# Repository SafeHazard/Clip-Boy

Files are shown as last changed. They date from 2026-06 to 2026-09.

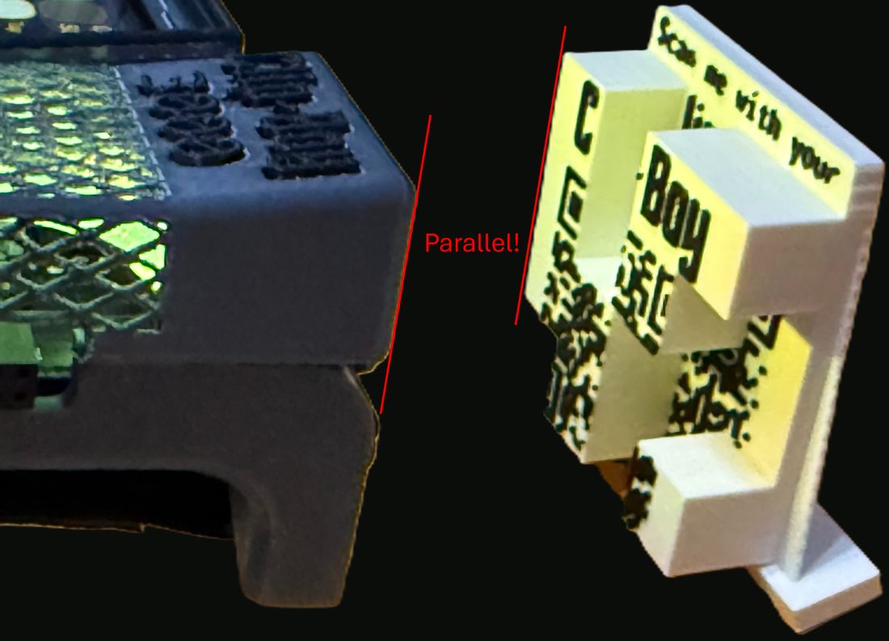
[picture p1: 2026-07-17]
help/img/scan-parallel.jpg

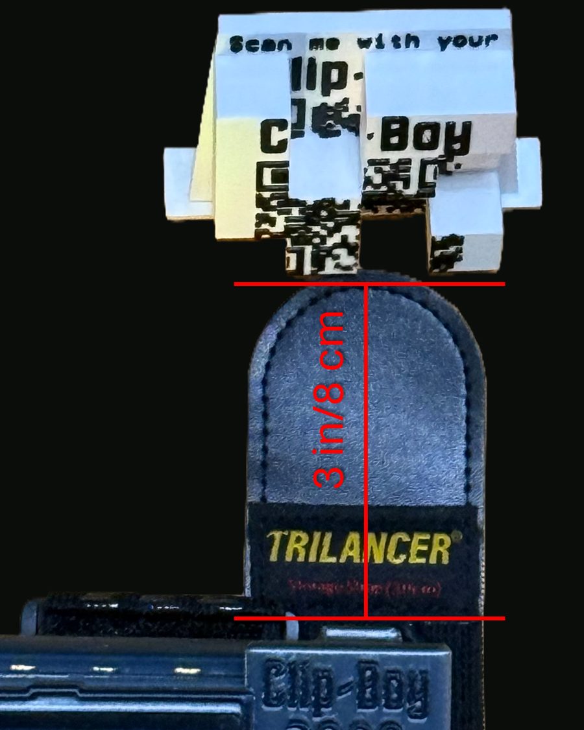
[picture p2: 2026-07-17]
help/img/scan-distance.jpg

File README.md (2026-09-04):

# Clip-Boy

Clip-Boy is an open-source DEF CON electronic badge with a digital wasteland
survivor soul, running on an ESP32-S3 with an LVGL touch UI.

> **Want one?** https://brycebadges.com  -  Docs & help: https://safehazard.github.io/Clip-Boy

## Who built this
Clip-Boy is Bryce's project. He did the PCB design, the enclosure, and the
firmware. Commits land under `tropicsquirrel` (his dad) because the build toolchain
lives on that machine - it reflects where the work was committed from, not who did
it. Claude is used heavily throughout; see `Clip-Boy/AI-DISCLOSURE.md`. Outside
contributions are credited below and in the commit/PR history.

## Repository layout
- **`Clip-Boy/`** - the firmware (Arduino sketch `Clip-Boy.ino` + sources, vendored
  `Clip-Boy/libs/`, build scripts in `Clip-Boy/scripts/`).
- **`Clip-Boy/hardware/`** - open-hardware package to build your own badge: bill of
  materials (`BOM_*.md`/`.csv`), PCB source (`Clip-Boy-PCBs.eprj2`, EasyEDA) + fab-ready
  Gerbers for both boards, the enclosure (`Enclosure-*.step`), and the OmniTag HR-code
  master (`omnitag.3mf`).
- **`Clip-Boy/tags/`** + **`Clip-Boy/stands/`** - ready-to-print `.3mf` models: one
  collectible HR-code tag per ID, plus display stands (regenerate any time with
  `Clip-Boy/scripts/build_all_tags.py`). Print assets only - not needed to compile.
- `index.html`, `postcon/` - the project's web pages. `README.md`, `LICENSE`.

## License
**GPLv3** (`LICENSE`, repo root) - forced by linking the GPL `audio-tools` library.
First-party code is also offered under MIT for audio-tools-free builds. Third-party
components: `Clip-Boy/THIRD_PARTY.md`. AI disclosure: `Clip-Boy/AI-DISCLOSURE.md`.
Acceptable use: `Clip-Boy/acceptable_use.md`.

## Credits
- **ESP32 Marauder** by **[JustCallMeKoko](https://github.com/justcallmekoko)**
  ([justcallmekoko/ESP32Marauder](https://github.com/justcallmekoko/ESP32Marauder)) - the
  backbone of the badge's WiFi/Bluetooth recon toolset.
- **Drone Remote-ID detector** (ASTM F3411 / Open Drone ID) contributed by
  **[zenrandom](https://github.com/zenrandom)** - the companion transmitter/simulator toolkit
  lives at **[SafeHazard/drone-remoteid](https://github.com/SafeHazard/drone-remoteid)**.

Full on-device credits are under **Settings > Credits**; third-party components in
`Clip-Boy/THIRD_PARTY.md`.

## Build setup
Versions are pinned for reproducibility:
- **Git Bash** (Windows) to run the build scripts: https://git-scm.com/download/win
  (macOS/Linux already have bash). **Python 3.9+**: https://www.python.org/downloads/
- **`arduino-cli`** (1.4.x).
- **ESP32 core `esp32:esp32@2.0.10`** - REQUIRED, exact version (what the signed
  releases are built with; a different core = a different, non-reproducible binary):
  ```bash
  arduino-cli core install esp32:esp32@2.0.10
  ```
  `build.sh` enforces this and injects the ClipBoy linker flags itself, so **no
  `platform.txt` hand-patching** is needed (unlike a stock Marauder setup).
- Third-party libraries are **vendored** in `Clip-Boy/libs/` - nothing to fetch.

## Build
```bash
cd Clip-Boy
bash scripts/build.sh              # Sn34k-Boy (default, listen-only)
bash scripts/build.sh --res34rch   # Res34rch-Boy (active research tools)
```
Flags compose: `--test`, `--rift` (alt boot screen), `--upload --port COMx`.

## Reproducibility
Builds are deterministic (stamp derived from the commit or a pinned `VERSION`, and
the build path is stripped from the image). From the exact release commit (with the
real `secret.h` + the release `VERSION`), the owner reproduces the signed release
byte-for-byte; a public builder gets a **functionally identical** badge (a fixed ~64
bytes of metadata differ: the ELF self-hash + the esptool image hash). The sketch is
`Clip-Boy.ino` here; the official signed releases are built from the same name.

## The ARG secret
The badge's ARG finale derives phone-unlock codes from a private HMAC key that is
**not** in this repo: `arg_unlock.h` compiles an all-zero placeholder by default, so
the firmware builds and runs (everything works except matching the live phone/IVR).
Define your own 32-byte key to run your own finale.

## Fonts (verify licensing for YOUR use)
The UI typeface (**monofonto**) and tag typeface (**Trek**) are **not included**;
the pre-generated glyph headers (`ui_font_pipboy_*.c`) ARE, so the firmware builds
without them. You only need the `.otf` files to *regenerate* fonts or build the tags.
We don't host or vouch for these fonts - check the license for your use:
monofonto https://www.dafont.com/monofonto.font  -  Trek https://font.download/font/trek

## Legal
Clip-Boy is an independent, original design. It is **not affiliated with, endorsed
by, or sponsored by** any other company, and it is not a replica of any existing
product. Use the badge's tools only on networks and devices you own or are
authorized to test - see `Clip-Boy/acceptable_use.md`.

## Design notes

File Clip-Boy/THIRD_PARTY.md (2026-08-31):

# Third-party libraries (vendored)

To make a fresh clone build with no external fetches, the third-party Arduino
libraries Clip-Boy links are **vendored** into [`libs/`](libs) — copied in and
trimmed to what compiles (each library's `src/`, root sources, manifest, and
license; `examples/`/`docs/`/`tests/` removed). Re-vendor with
[`scripts/vendor_libs.sh`](scripts/vendor_libs.sh).

Each library keeps its own license file under `libs/<name>/` — **that file is
authoritative.** The table below records provenance (version + upstream) and the
license as a convenience; see also [`LICENSE.md`](LICENSE.md). The combined
firmware is GPLv3 (see `LICENSE.md` for why).

| Library | Version | Upstream | License |
|---|---|---|---|
| lvgl | 9.2.0 | github.com/lvgl/lvgl | MIT |
| LovyanGFX | 1.2.19 | github.com/lovyan03/LovyanGFX | BSD-2-Clause (FreeBSD) |
| audio-tools | 1.1.2 | github.com/pschatzmann/arduino-audio-tools | GPL-3.0 |
| minimp3 | 0.1.0 | github.com/pschatzmann/arduino-minimp3 (lieff/minimp3) | CC0-1.0 (public domain) |
| NimBLE-Arduino | 2.3.7 | github.com/h2zero/NimBLE-Arduino | Apache-2.0 |
| ArduinoJson | 7.4.2 | github.com/bblanchon/ArduinoJson | MIT |
| Adafruit_NeoPixel | 1.15.2 | github.com/adafruit/Adafruit_NeoPixel | LGPL-3.0 |
| SparkFun_VL53L5CX_Arduino_Library | 1.0.3 | github.com/sparkfun/SparkFun_VL53L5CX_Arduino_Library | MIT |
| ESPAsyncWebServer | 2.10.4 | github.com/mathieucarbou/ESPAsyncWebServer | LGPL-3.0 |
| AsyncTCP | 1.1.4 | github.com/mathieucarbou/AsyncTCP | LGPL-3.0 |
| ESP32Ping | 1.7 | github.com/marian-craciunescu/ESP32Ping | (see library) |
| LinkedList | 1.3.3 | github.com/ivanseidel/LinkedList | MIT |
| lz4-1.10.0 | 1.10.0 | github.com/lz4/lz4 (Arduino packaging) | BSD-2-Clause |
| ClipBoy | 1.0.0 | fork of github.com/justcallmekoko/ESP32Marauder | MIT |
| opendroneid-core-c | vendored source | github.com/opendroneid/opendroneid-core-c | Apache-2.0 |
| ClipBoyTheremin | 1.0.0 | first-party (this project) | GPL-3.0 |
| LovyanInit-Waveshare | 0.1.0 | first-party (this project) | GPL-3.0 |
| HRCode4x4 | 1.0.0 | first-party (this project) | GPL-3.0 |
| HRScanGuidance | 0.1.0 | first-party (this project) | GPL-3.0 |

**opendroneid-core-c** (the ASTM F3411 / Open Drone ID decoder that powers the
Detect ▸ Drone ID Remote-ID tool) is vendored as source *inside* the ClipBoy
library — `libs/ClipBoy/src/odid_decode.c` + `opendroneid.h` — rather than as its
own `libs/<name>/` directory. Its Apache-2.0 license text is kept beside those
files at `libs/ClipBoy/src/LICENSE.opendroneid`, and each file retains its SPDX
`Apache-2.0` header + `Copyright (C) 2019 Intel Corporation`. Apache-2.0 is
one-way compatible with the combined GPLv3 firmware.

`libs/lv_conf.h` is our LVGL configuration (LVGL reads it from the folder above
`libs/lvgl/`). Notably `LV_USE_FS_ARDUINO_ESP_LITTLEFS = 0` — see CLAUDE.md.

## Fonts

| Font | Source | License | Used for |
|---|---|---|---|
| Monofonto | Larabie Fonts (external, not committed) | freeware; embedded glyphs only | `ui_font_pipboy_*.c` (the Pip-Boy UI typeface) |
| Noto Emoji | google/fonts `ofl/notoemoji` (static instance in [`assets/fonts/`](assets/fonts)) | OFL-1.1 (`assets/fonts/OFL.txt`) | `ui_font_emoji_14.c` — 24-emoji fallback subset |

The `ui_font_*.c` files are **generated, committed artifacts** (the rendered
glyph bitmaps, not the source outlines). Regenerate with
[`scripts/build_fonts.sh`](scripts/build_fonts.sh). Monofonto's OTF is not
redistributed (font EULA); set `MONOFONTO_OTF` to point the script at it. Noto
Emoji is OFL, so its static instance is vendored for reproducibility.

## Local modifications to vendored libraries

Kept minimal; each is commented in-place with a `Clip-Boy local patch` marker so
it survives review and is easy to re-apply after a re-vendor.

- **SparkFun_VL53L5CX_Arduino_Library** — `begin()` is made idempotent
  (`SparkFun_VL53L5CX_Library.cpp`): it now frees `Dev` + `VL53L5CX_i2c` before
  re-`new`-ing them, and the two pointers are default-initialized to `nullptr`
  in the header. Upstream `begin()` allocates both unconditionally with no
  destructor, so every repeated `begin()` orphaned ~2.7 KB. The theremin
  re-`begin()`s the sensor on each enable, which leaked ~2,768 B per on/off
  cycle (caught by `scripts/tests/test_mutual_exclusion.py` / `probe_leak.py`).
  Re-apply if you re-vendor this library.

- **ClipBoy (PCAP single-owner + LittleFS fallback, DC34-147)** — the host badge
  owns the one global Arduino `SD` (mounted on HSPI in `coll_init`), so ClipBoy
  must not re-`SD.begin()`. Patches: `ClipBoyMarauder::setSDAvailable(bool)`
  (`ClipBoyMarauder.cpp/.h`) lets the badge flag the card up so PCAP uses the
  shared mount; `WiFiScan::startPcap` (`WiFiScan.cpp`, + `#include <LittleFS.h>`)
  prefers SD and falls back to the badge's LittleFS partition (size-capped to
  free − 768 KB so a capture can't starve CSV/.sav/radio data); `Buffer`
  (`Buffer.cpp/.h`) gains `setMaxBytes()` + a `writtenBytes` cap enforced in
  `saveFs()`. Each marked `Clip-Boy local patch (DC34-147)`. Re-apply on
  re-vendor.

- **ClipBoy (Settings in-memory only, no SPIFFS rewrite, DC34-147 perf)** —
  `Settings::saveSetting<bool>` (both `bool` and `String` value overloads,
  `Settings.cpp`) no longer rewrites `/settings.json` to SPIFFS; it updates only the
  in-memory `json_settings_string` that `loadSetting<>()` reads. The full-file
  re-serialize was a ~1-2s synchronous flash write that froze the UI when SavePCAP was
  toggled from a touch handler. Clip-Boy relies on none of Marauder's SPIFFS
  persistence (SavePCAP re-syncs from our NVS every boot; WiFi creds pass directly to
  `joinWiFi`). Marked `Clip-Boy local patch (DC34-147 perf)`. Re-apply on re-vendor.

- **ClipBoy (PCAP-only capture gated on 'Allow PCAP Saving', DC34-147)** — Raw/PCAP and
  PMKID/EAPOL are file-only captures; with saving off they'd run and write nothing. Gated
  at two layers so EVERY entry path errors cleanly: the Marauder CLI handlers `sniffraw`
  and `sniffpmkid` (`CommandLine.cpp`) return early with a message; `WiFiScan::RunRawScan`
  (pcap branch only — signal-strength monitor stays available) and `RunEapolScan`
  (`WiFiScan.cpp`) bail before `startPcap`. Gate reads `settings_obj.loadSetting<bool>
  ("SavePCAP")`. Marked `Clip-Boy local patch (DC34-147)`. Re-apply on re-vendor.

- **ClipBoy (MAC-tracker Serial writes made non-blocking, DC34)** — `WiFiScan::updateTrackerUI`
  (`WiFiScan.cpp`) ran every 1s on core 1 (via `cb.loop()` immediately before
  `lv_timer_handler`) and emitted ~21 unconditional `Serial` writes/sec. With no host
  draining the USB-CDC TX buffer each `write` blocked up to `setTxTimeoutMs` (50ms),
  stalling core 1 ~1s out of every 1s → the MAC-tracker UI froze regardless of packet
  density. Each write (`---`, `FOLLOWING`, per-entry MAC/frame line) is now guarded on
  `Serial.availableForWrite()`, so a serial-CLI user still sees the dump (their monitor
  drains the buffer → room available) while a touch-UI user with no reader skips it (buffer
  full) and never blocks. Deliberately NOT `DEBUG_VERBOSE`-gated, to preserve CLI output.
  Marked `Clip-Boy local patch (DC34)`. Re-apply on re-vendor.

- **ClipBoy (Raw/PCAP UI-freeze: rate-limit the pcap flush, DC34)** — `ClipBoyMarauder::loop()`
  (`ClipBoyMarauder.cpp`) called `buffer_obj.save()` EVERY loop; `Buffer::save`/`saveFs` does a
  full open+append+close to SD/LittleFS, and during Raw/PCAP capture the RX buffer is refilled
  continuously, so core 1 did tens of ms of blocking file I/O per loop right before
  `lv_timer_handler()` -> the UI froze. Now flushed at most every 150ms (RAM double-buffer absorbs
  the gap; `save()` early-returns when empty, so non-capture tools are unaffected). Marked
  `Clip-Boy local patch (DC34)`. Re-apply on re-vendor.

- **ClipBoy (Raw/PCAP Serial storm made non-blocking, DC34)** — `WiFiScan::renderRawStats`
  (`WiFiScan.cpp`) emitted ~11 unconditional `Serial.println` at 1Hz on core 1; with no host
  draining USB-CDC each blocked up to `setTxTimeoutMs` (50ms) -> ~0.5s core-1 stall/sec. Same

  > ⚠ 2026-07-27: the badge now runs a **0 ms** TX timeout until a host actually reads it
  > (`cb_serial_tx_relax()` in `Clip-Boy.ino`), so the no-reader case no longer blocks.
  > These guards still apply when a monitor IS attached. Measured: the 50 ms default was
  > costing every passive WiFi tool ~60% of its frames (`docs/test-reports/h1-cdc-stall-2026-07-27.md`).
  fix as the MAC dump: the whole block is guarded on `Serial.availableForWrite()` (a serial-CLI
  reader still sees it; no reader skips it). Marked `Clip-Boy local patch (DC34)`. Re-apply on re-vendor.

- **ClipBoy (stale-accumulator clean-slate on tool start, DC34)** — Marauder-side accumulators
  the UI reads persisted across tool switches, so a tool could display a PRIOR tool's data (e.g.
  Raw/PCAP showed a stale `num_probe` from a Monitor run; MAC Tracker/BT/Flock/Pwnagotchi lists
  showed old rows on re-open). `StopScan` only resets `*_frames` (not `num_*`) and never touched
  the device lists; three `clear*` fns were dead code. Added `ClipBoyMarauder::resetDisplayAccumulators()`
  (`ClipBoyMarauder.cpp/.h`) — called on every tool start from `dispatch_clipboy_action` — which
  runs `resetPacketCounters()` + `clearBTDevices/clearFlockDevices/clearPwnagotchis` (were dead) +
  two new `WiFiScan::clearMacTracker()` (wipes the `mac_entries` hash table `clearMacHistory` misses)
  and `clearChannelActivity()` (`WiFiScan.cpp/.h`). Deliberately does NOT clear the AP/STA/SSID
  lists (select-then-run inputs). Also exposed `reqFrames`/`respFrames` in `CBPacketCounters` so
  Raw/PCAP shows real probe counts. Marked `Clip-Boy local patch (DC34)`. Re-apply on re-vendor.

- **ClipBoy (Raw/PCAP channel hop + selector, DC34)** — Raw/PCAP was FIXED-channel (parked on
  whatever `set_channel` it inherited), so it captured 0 beacons on a quiet channel. `packetRateLoop`
  (`WiFiScan.cpp`) now `channelHop()`s ~1s/channel during `WIFI_SCAN_RAW_CAPTURE` when the new
  `raw_hop` flag is set (EAPOL is never hopped — a handshake must stay on the target channel). Added
  `WiFiScan::setRawChannel(uint8_t)` + `ClipBoyMarauder::setRawCaptureChannel(uint8_t)` (0 = hop the
  band = the UI "Hop (all)" default; 1-14 = lock via `changeChannel`). The UI adds a Channel dropdown
  to the Raw/PCAP pane. Marked `Clip-Boy local patch (DC34)`. Re-apply on re-vendor.

- **ClipBoy (EAPOL capture: counter + target-channel lock, DC34)** — the badge never registered
  EAPOL. Two bugs in `WiFiScan.cpp`: (1) Raw/PCAP's `0x888e` ethertype check was nested under the
  `WIFI_PKT_MGMT` branch, but EAPOL is a 802.11 DATA frame -> it fell into `data_frames++` and the
  check never ran (EAP:0 while the handshake WAS written to the pcap); moved it into the data branch.
  (2) `RunEapolScan` sat on a stale `set_channel` and the EAPOL loop hopped all 14 channels every 2s,
  so a <100ms handshake almost never coincided; now it locks to the SELECTED AP's channel and only
  hops (`eapol_hop`) when no AP is selected. Marked `Clip-Boy local patch (DC34)`. Re-apply on re-vendor.

- **ClipBoy (large PSRAM capture buffer, DC34)** — `Buffer` used two 8KB (`BUF_SIZE`) internal-RAM
  buffers; on a capture burst (a 4-way handshake amid beacons) both filled before the slow SD write
  drained and packets dropped (missed EAPOL msg 2/4). Now lazily allocates two `CB_PCAP_BUF_SIZE`
  (128KB) PSRAM buffers on first capture (`Buffer::ensureBuffers`, `Buffer.cpp/.h`), with `bufCap`
  driving the fill checks and a fallback to `BUF_SIZE` internal RAM if `ps_malloc` fails. Marked
  `Clip-Boy local patch (DC34)`. Re-apply on re-vendor.

- **ClipBoy (expose Channel-Activity page, DC34)** — the ranged channel-activity hop only
  sweeps 7 channels per `activity_page` (page 1 = ch 1-7, page 2 = ch 8-14) and the vendored
  default is stuck at page 1, so a "channels 1-14" histogram left ch 8-14 permanently empty.
  Added `ClipBoyMarauder::setChannelActivityPage(uint8_t)` + `getChannelActivityPage()`
  (`ClipBoyMarauder.cpp/.h`) writing the public `wifi_scan_obj.activity_page`; the UI cycles
  it 1↔2 each poll tick so all 14 channels sample. No WiFiScan edit (member already public;
  picked up on the next 100ms hop). Marked `Clip-Boy local patch (DC34)`. Re-apply on re-vendor.

- **ClipBoy (CLI `help` reflects actual hardware/edition, DC34)** — the upstream
  Marauder `help` printer advertised commands ClipBoy can't run: the GPS family
  (`gps`/`gpsdata`/`nmea`/`gpspoi`/`gpstracker`) and `led` (Marauder's neopixel
  path is absent — badge LEDs use `neopixel_driver.h`). The GPS help lines are now
  `#ifdef HAS_GPS` (matching the already-gated dispatch + the existing `wardrive`
  pattern); the `led` help line is removed; `HELP_UPDATE_CMD_A` drops the dead
  `-w` (OTA) option (only `-s`/SD works). `CommandLine.cpp` + `CommandLine.h`. The
  active-TX tools were already `#ifdef CLIPBOY_RES34RCH`-gated (proven by
  `check_sku_binaries.py`) — unchanged. Re-apply on re-vendor.

- **ClipBoy (Evil Portal per-activation DRAM leak, DC34)** — each Evil Portal Start
  re-ran `setupServer()` (~12 `server.on` handlers) + `new CaptiveRequestHandler()` +
  `dnsServer.start()`, while Stop (`EvilPortal::cleanup`) freed only the PSRAM HTML — so
  every Start/Stop cycle leaked the DNS UDP pcb + SoftAP netif/DHCP pool and grew
  `server._handlers` unbounded (the integration test measured ~21 KB on first activation,
  ~2 KB/cycle after). Fix (`EvilPortal.cpp`): `startAP()` registers the web endpoints +
  captive handler ONCE (`static bool s_server_registered`); `cleanup()` now
  `dnsServer.stop()` + `WiFi.softAPdisconnect(true)`. The AsyncTCP service task (~16 KB,
  one-time, shared) is deliberately left alone. Marked `Clip-Boy local patch (DC34 heap-leak)`.
  Re-apply on re-vendor.

- **ClipBoy (active-TX UI FPS: cap per-call TX burst, DC34)** — active-transmit modes ran
  their whole packet burst inline in one `wifi_scan_obj.main()` call, starving
  `lv_timer_handler()` (runs once/loop): Beacon Spam Funny sent 7×12=84 `broadcastSetSSID`
  (+ a redundant `delay(1)` each) per call → ~9 fps and a 7-10 s start stall;
  Beacon-Random/Flood-Auth/Deauth sent 55/call. `WiFiScan.cpp`: Funny `7→1`, Beacon Random
  `55→8`, Auth/Deauth `55→15`, and dropped the redundant per-send `delay(1)` in
  `broadcastSetSSID` (`changeChannel()` already settles 1 ms). The bursts were sized for the
  old BLOCKING M5Stick UI; our non-blocking LVGL loop runs proportionally more often, so
  aggregate TX rate is ~unchanged. Marked `Clip-Boy local patch (DC34 fps)`. Re-apply on
  re-vendor. ⚠ verify TX still radiates with an external receiver (badge counters can mask it).

- **ClipBoy (SAE-commit `current_act` cross-task UAF hardening, DC34)** — `getSAEACT`
  (`WiFiScan.cpp`) ran `free(current_act); current_act = malloc(n); memcpy(...)` on a global
  heap pointer **inside the promiscuous RX callback** (`beaconSnifferCallback`, WiFi-driver
  task), while the main-task SAE flood (`sendSAECommitFrame`) is written to read `current_act[]`
  — a cross-task use-after-free (a beta tester's SCA finding; currently non-crashing only because
  `current_act_len` is never assigned, so the read is dead — a latent landmine). Replaced the
  heap pointer with a fixed static `current_act_buf[255]` (never freed) published under a new
  `portMUX` spinlock `current_act_mux`, with the copy length clamped; the reader copies under the
  same lock and re-clamps. No heap ops in the RX callback, no UAF, no OOB. Marked `Clip-Boy local
  patch (DC34)`. Re-apply on re-vendor. Upstream PR drafted — see `docs/prs/marauder-concurrency-prs.md`
  (PR-1), along with the wider audit of the same bug class (device-list/String races, Evil Portal
  creds, PCAP Buffer) for contribution back to justcallmekoko/ESP32Marauder.

- **ClipBoy (cross-task concurrency audit — 4 more fixes, DC34)** — a 4-agent hunt for the
  `current_act` bug class across the tool corpus found the SAME cross-task pattern LIVE (it was only
  dead-code-defused at the SAE spot). All fixed in `libs/`; upstream PR drafts in
  `docs/prs/marauder-concurrency-prs.md`:
  - **Device lists (`AccessPoint`) — the big one.** `access_points`/`stations` are mutated from 6
    sniffer RX callbacks (WiFi task) and copied by-value by the main-task UI/attack readers; the
    `String essid`/`man` fields would free+realloc their heap buffer during that copy → cross-task
    UAF/heap-corruption. **POD-ified `AccessPoint`** (essid/man → `char[33]`; `EvilPortal.h`) so the
    by-value copy is a plain memcpy; converted every String-idiom site in `WiFiScan.cpp`/
    `ClipBoyMarauder.cpp`/`CommandLine.cpp`. Plus NULL-guards in `LinkedList::set`/`operator[]`
    (`libs/LinkedList/LinkedList.h`) — `getNode()`'s shared node cache can be corrupted by a
    concurrent access, returning NULL for an in-range index → the old unconditional `->data` deref
    crashed (write-to-null).
  - **Evil Portal captured creds + `index_html` (`EvilPortal.cpp`/`.h`).** `user_name`/`password`
    `String`s reassigned by the `/get` handler (AsyncTCP task) while the main task read them →
    String UAF; now fixed `char[64]` buffers guarded by a `portMUX` (`cred_mux`). And `cleanup()` no
    longer `free()`s `index_html` while app-lifetime web handlers may still stream it (kept for the
    app lifetime, reused).
  - **`analyzer_name_string` (`WiFiScan.cpp`/`.h`).** Channel-Analyzer name reassigned in the RX
    callback, `.c_str()`-read on main → String UAF; now a `char[33]` behind guarded
    `setAnalyzerName`/`getAnalyzerName` accessors (`analyzer_name_mux`).
  - **PCAP `Buffer` (`Buffer.cpp`/`.h`).** The `while(saving)delay()` busy-wait was a TOCTOU
    (main-task `save()` zeroed sizes while the RX callback wrote); now a `portMUX` ping-pong swap
    (snapshot+flip under lock, drain outside). Also dropped the per-frame NVS read (`loadSetting`
    on every captured frame) — `append()` gates on `writing` instead.
  All marked `Clip-Boy local patch (DC34)`; re-apply on re-vendor.

## Not vendored

- **ESP32 board core** (`esp32:esp32` 2.0.10) and its bundled libraries (WiFi,
  FS, SD, SPI, LittleFS, Preferences, Wire, …) — these are part of the platform,
  installed via arduino-cli (see README). Pin this version for reproducibility.
- **libhelix** was removed entirely (replaced by minimp3) to drop its
  GPL-incompatible RPSL licensing.

## Updating a vendored library

Vendoring pins these versions. To update one, replace the upstream copy and
re-run `scripts/vendor_libs.sh`, then rebuild and re-test. (Re-apply the
LovyanGFX CJK-font trim if you re-vendor it — the script does this.)

- **`WiFiScan.cpp` `RunEvilPortal` + `EvilPortal.cpp` credential append** — *Clip-Boy local patch (audit 2026-07-24 SB4 / 2026-07-28 SB4b).* Both halves of the Evil Portal credential sink are compile-gated behind `CB_EVIL_PORTAL_LOG_SD` (unset by default): the `startLog("evil_portal")` file AND the `buffer_obj.append(line)` that would otherwise inherit an open pcap and flush harvested credentials to SD/LittleFS. **Re-apply on re-vendor.** Release gates `SB4` + `SB4b` fail the build if either half is dropped FROM THE FILE IT GUARDS (`WiFiScan.cpp` / `EvilPortal.cpp` respectively) -- so a lost patch breaks the build rather than silently shipping. ⚠ Scope honestly: neither gate would catch the credential write being MOVED to a different translation unit. They are regression guards on two known sites, not a proof that no credential reaches storage.

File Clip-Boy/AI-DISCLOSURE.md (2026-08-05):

# AI & tooling transparency

Bryce designed the PCB and enclosure, defined the feature set, and made every
call about what ships and what gets cut. Everything was tested on physical
hardware (some of it gloriously flaky).

Tools used along the way:

- **Claude + Claude Code** — code review, PCB review, debugging partner
- **ESP32 Marauder** by justcallmekoko — base for the Wi-Fi/BLE security tooling,
  ported to Clip-Boy with significant AI-assisted refactoring
- **Gemini** — collectible artwork (prompts written and curated
  by Bryce)
- **Adobe Firefly** — image refinement and cleanup
- **ChatGPT** — a handful of static graphics, including Clippy
- **Suno** — instrumental music beds for the "SegFault-Tec FM" radio feature
  (commercial-tier license that grants ownership; original instrumental, never "in
  the style of" a named artist)
- **ElevenLabs** — the synthetic radio DJ voice (commercial tier; an owned,
  synthetic voice — never a clone of any real person)
- **Programmatic (sox / Python)** — radio tones, numbers-station digits, and static
  (fully original, no licensing)

AI was used as a tool, like Git or a multimeter. The decisions, the design, the
bugs, and the jokes are all Bryce's.

---

This disclosure is also surfaced on the badge itself (STATS → Settings → Legal →
*AI Disclosure*).

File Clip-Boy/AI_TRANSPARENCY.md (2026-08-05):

# AI Transparency — Clip-Boy

How we talk about AI use in Clip-Boy: what we say, where we say it, and why.

This is a *positioning* document, not a license or legal disclosure. The legal disclaimers live in the on-badge `Settings > Legal` screen and the website footer. This document covers the marketing/communication surface around AI use in the design and production of Clip-Boy.

## TL;DR

- Be specific about what AI did and what Bryce did. Vagueness reads as cover; specificity reads as competence.
- Lead with the human craft (PCB, enclosure, hardware drivers, product vision) before naming AI tools by name and role.
- Disclose proactively in three places: on-badge Credits, website About, and the Reddit launch post body. Don't disclose in the video itself.
- Avoid the term **"vibe coded"** — it's a tripwire term in 2025–26 hacker culture. Use **"AI-assisted"**.
- Bryce's prior delivered Kickstarter (DC33 Space Badge, 219% funded, 100% delivery, before AI was in his workflow) is the load-bearing trust signal. Reference it whenever AI is mentioned.

## Why this framing

### The DEF CON tolerance test isn't tool use — it's ownership

DEF CON's audience has used IDA, Ghidra, Burp, Metasploit, Wireshark for decades. They don't object to power tools. They object to people who don't understand what they shipped. The hostility around AI in 2025–26 is *specifically* at "vibe coders" — people who chained prompts until something ran and then sold it. It's not at engineers who used AI as a force multiplier and stayed in the driver's seat.

Specificity is the difference. *"Claude Code reviewed and audited the firmware; I made all hardware, PCB, BOM, and product decisions; 95 collectible artworks were generated with Gemini"* reads as a real engineer who knows what each tool did. Vague *"AI-powered"* reads as cover.

### Disclosure failure modes

| Failure mode | Outcome |
|---|---|
| AI use hidden, then discovered | Catastrophic. Every documented backlash (Terraforming Mars KS, Awaken Realms Puerto Rico, WotC) followed this pattern. |
| AI listed as a feature without specifics | Reads as marketing-speak. Audience smells it. |
| AI acknowledged but human craft buried | Reads as "AI did the work, human pressed go." |
| Human craft front-and-center, AI tools named with specific role | Wins. Industry standard for legitimate AI-assisted engineering. |

Kickstarter has required AI disclosure since August 2023; non-disclosure → suspension. So even if you wanted to hide it, you couldn't.

### Why the "Bryce shipped before AI" line is load-bearing

The single most important credibility move is anchoring AI as a *current tool* of an *already-shipping engineer*, not as the thing that made shipping possible. The DC33 Space Badge proves Bryce can build, ship, fulfill, and execute hardware before AI was in his workflow. Mentioning AI without that anchor invites the question *"did the AI build it?"*. Mentioning AI *with* that anchor reframes the question to *"how does he use AI now?"* — which is a friendly question, not a hostile one.

## Three pieces of disclosure copy

### A. On-badge `Settings > Credits` screen

Most authentic placement — this is the page DEF CON people will actually look at. Tone: matter-of-fact, no marketing fluff, hacker-respectful.

```
CREDITS

Clip-Boy is built and maintained by Bryce (17).

Hardware: custom PCB, enclosure, and full electronics
integration done by hand. Every driver — touch, display,
NeoPixels, I2S audio, VL53L5CX sensor — was hand-tuned
and debugged on real hardware.

AI tools used:
  Claude Code — code review, refactoring, and rubber-duck
    debugging across most of the firmware. Every suggestion
    was read, tested, and either kept, rewritten, or thrown
    out.
  Gemini — generated the 95 collectible artworks from
    prompts I wrote and curated.
  Adobe Firefly, ChatGPT — image cleanup and a few static
    graphics (including Clippy).
  Suno — instrumental music beds for the SegFault-Tec FM
    radio (commercial-tier, owned).
  ElevenLabs — synthetic radio DJ voices (owned; never a
    clone of a real person).
  Claude — copy editing on legal and marketing text.

Architecture, design choices, and the bugs are mine.

Inspired by Fallout. Not affiliated with Bethesda,
Microsoft, or Clippy.
```

**Design choices:**
- Hand-built hardware named *first* — the part skeptics will assume was AI is named first as human work, so the disclosure reads as confidence, not confession.
- "The bugs are mine" — hacker-credibility tell. Real engineers say this.
- AI tools named *by name* — Claude Code, Gemini. Specificity over hand-waving.

### B. Website `grab.brycebadges.com` "About the creator: Bryce"

Narrative paragraph. Tone: confident, specific, slightly dry. Should normalize AI use the way good carpenters normalize power tools.

```
Bryce is 17 and builds badges out of Texas. Clip-Boy is
his second hardware project; the first was a DEF CON 33
Kickstarter that funded at 219% and shipped 100% on time,
before he was using AI for much of anything.

He designed the PCB, modeled the enclosure, and wrote the
firmware that drives the touchscreen, NeoPixels, audio, and
LiDAR sensor. He uses Claude Code as a code reviewer and
debugging partner — roughly 70% of the firmware passed
through it at some point, and none of it shipped without
him reading, testing, and often rewriting it. The 95
collectible artworks were generated with Gemini from prompts
he wrote and curated, with Adobe Firefly and ChatGPT for
cleanup and a few static graphics. The SegFault-Tec
FM radio's instrumental music beds were made with Suno and its
synthetic DJ voices with ElevenLabs (both commercial-tier and
owned; the voices are synthetic, never clones of real people).
A few legal and marketing paragraphs were tightened with AI
copy editing.

Everything that touches the hardware was hand-tuned on real
silicon. Every design call — what goes on the badge, what
gets cut, what the jokes are — is his.

College fund, not a startup.
```

**Design choices:**
- Kickstarter line establishes "ships without AI" *before* AI is mentioned, so AI lands as a tooling choice, not a crutch.
- "70%" — concrete percentage reads as a real engineer who has measured, not a marketer making claims. **Adjust this number to whatever's actually accurate.**
- "Hand-tuned on real silicon" — the phrase real engineers use; signals competence.
- "College fund, not a startup" — disarms cynicism without begging.

### C. Reddit post body — pre-empt paragraph

For the bottom of the launch post. Designed to *pre-empt* the inevitable "did you just vibe code this" comment by naming the question first.

```
Pre-empting the obvious question: yes, I use AI. Claude Code
reviewed most of the firmware, Gemini generated the 95
collectible images from my prompts, and the radio's music and
DJ voices are Suno and ElevenLabs (commercial-tier, owned).
The PCB, the enclosure,
every hardware driver, and every design call are mine —
hand-tuned on real silicon. I don't ship code I can't
explain line by line, and AI doesn't fix bad architecture.
Ask me anything in the comments.
```

**Design choices:**
- Opens by *naming* the question instead of dodging it. Disarms the asker.
- Concrete tool names mean nobody has to dig.
- "I don't ship code I can't explain line by line, and AI doesn't fix bad architecture" — peer-to-peer signal that he understands what AI is and isn't good for. This sentence is the load-bearer.
- "Ask me anything" turns the comment section from interrogation into conversation.

## Placement summary

| Where | Disclosure level | Tone | Length |
|---|---|---|---|
| **On-badge `Settings > Credits`** | Most detailed | Engineering-log | ~150 words |
| **Website "About the creator"** | Narrative | Confident, slightly dry | ~180 words |
| **Reddit post body** | Concise + AMA invite | Peer-to-peer | ~70 words |
| **Promo video body** | None | — | (let the silicon-shots speak; the medium itself shows hand-craft) |
| **Promo video end card** | Optional one-frame factual line | Tiny | ~15 words |

Optional video end-card line, if used:

> *"AI tools: Claude Code (firmware), Gemini (art), Suno + ElevenLabs (radio). Hardware, design, and bugs by Bryce."*

## Words and phrases to avoid

| ❌ Avoid | ✅ Prefer | Why |
|---|---|---|
| "vibe coded" | "AI-assisted" | Tripwire term in 2025–26. "Vibe coded" specifically means *shipped without comprehension*. |
| "Made with ChatGPT" | "Reviewed/audited by Claude Code" | "Made with X" reads as the AI shipped it. "Reviewed by X" reads as a process step. |
| "AI-powered firmware" | "Custom firmware" | "AI-powered" suggests AI on the device. The badge has no AI on it. |
| "Revolutionary AI integration" | (delete) | Marketing-speak invites scrutiny. |
| "Leveraged AI to..." | "Used Claude Code to..." | Corporate-speak triggers the sniff test. |

## Things to NOT do

1. **Don't lead with AI** anywhere except the Reddit pre-empt. Lead with hardware. AI mentions are second-order.
2. **Don't list AI as a product feature.** The badge has no AI capability on-device. AI is in the workflow, not the BOM.
3. **Don't preach about AI ethics** in marketing copy. Stay matter-of-fact.
4. **Don't apologize.** Good engineers use power tools. State it; move on.
5. **Don't claim more than is true.** If 70% of the firmware passed through Claude Code, say 70%. If it's 40%, say 40%. Engineers will sniff out exaggeration faster than understatement.

## Things you might add later

- **Proactive blog post:** *"How a 17-year-old built a DEF CON badge with AI as a co-pilot"*. Risky if not written well. Strong if it is. Defer until after the launch lands well.
- **Open-sourcing parts of the code post-launch.** Demonstrates that the firmware is real and review-able, not an AI-generated black box. Strongest possible trust signal — but don't promise this until you're ready to follow through.
- **A "what AI got wrong" appendix** to the credits screen. One or two short anecdotes about AI suggestions that were wrong and how Bryce caught them. Massive credibility move because it shows him as the editor, not the typist.

## Reference: research notes

Key sources used in shaping these recommendations:

- **"Vibe coded" pejorative status:** [Hackaday: Ask Hackaday — Vibe Coding](https://hackaday.com/2025/04/09/ask-hackaday-vibe-coding/), [HN: Vibe Code is Legacy Code](https://news.ycombinator.com/item?id=47566491), [Karpathy/Osmani — vibe coding ≠ AI-assisted engineering](https://medium.com/@addyosmani/vibe-coding-is-not-the-same-as-ai-assisted-engineering-3f81088d5b98)
- **Disclosure-then-trust pattern:** [MIT Sloan: AI Disclosures Build Trust](https://sloanreview.mit.edu/article/artificial-intelligence-disclosures-are-key-to-customer-trust/), [Kickstarter AI disclosure policy (Aug 2023)](https://help.kickstarter.com/hc/en-us/articles/16848396410267)
- **AI-art-as-deception backlash:** [CBR: KS bans projects with concealed AI art](https://www.cbr.com/kickstarter-bans-project-involving-ai-generated-art/), [Board Game Wire: Awaken Realms / Ravensburger](https://boardgamewire.com/index.php/2024/03/02/awaken-realms-pulls-ai-art-from-deluxe-puerto-rico-kickstarter-after-ravensburger-steps-in/)
- **DEF CON cultural context:** No documented "AI-shaming" of an indie *hardware* project surfaced. The famous AI backlash incidents are all in tabletop / illustration spaces. Hardware communities have been more tolerant because AI-as-tool for code is normalized.
- **Comparable-product positioning data:** [Tiiny AI Pocket Lab](https://www.startuphub.ai/ai-news/startup-news/2026/tiiny-ai-pocket-lab-hits-1m-on-kickstarter), [Particle Tachyon](https://www.kickstarter.com/projects/particle-iot/tachyon-powerful-5g-single-board-computer-w-ai-accelerator), [Space Badge / DC33 / Owen](https://www.kickstarter.com/projects/o-n/space-badge-the-next-generation-of-defcon-badges)

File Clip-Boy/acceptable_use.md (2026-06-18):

# Acceptable Use — CANONICAL source of truth

**Version:** v0.3 · **Status:** counsel-reviewed 2026-06-18 (Jira **DC34-99**);
adopts counsel's approved wording (indemnity expanded per counsel's note,
owner-approved). v0.3 (DC34-128): §2c Sn34k framing corrected — "passive ≠
harmless" (stock build's EAPOL/PMKID/PCAP capture can intercept). · **This is not
legal advice.**

> **Naming note:** counsel's returned draft referred to **Sn33k-Boy / L33t-Boy**
> (the pre-rename build names). This canonical uses the current product names
> **Sn34k-Boy / Res34rch-Boy** (rename finalized 2026-06-15) — a factual product-
> identifier swap, not a substantive change. Worth a one-line confirm to counsel.

This file is the single source of truth for Clip-Boy's acceptable-use / disclaimer
language. Every customer-facing surface — the **storefront**, the **web flasher**,
and the **badge firmware** (first-boot clickwrap + Tools banner + Legal page) —
renders the **same policy** at a length that fits the surface. When the policy
changes, bump the version here and re-sync each surface (see the sync table).
Reconciled from: Bryce's original draft + Tomas's edits, the `web_flash` and
`shop` agent drafts, and the ui_test 3-lens review panel (legal / firmware-UX /
web-flash-commerce).

> **Framing constraint (GPLv3 §7 — load-bearing, confirm with counsel):** this is
> an **assumption-of-risk / liability notice and a term of sale**, NOT a software
> license condition. Clip-Boy firmware is GPLv3; §7 forbids adding field-of-use
> restrictions, and such a restriction would be void and conflict with the GPL.
> Never reword any of this into "you are licensed to use this software ONLY IF…".
> "By using this you accept responsibility / consent to these terms" is fine;
> "you may only use this software for X" is not.

**Entities:** Sold by **Coruscant Productions LLC**. Surfaces:
`get`/`ks.brycebadges.com` (storefront), `flash.brycebadges.com` (web flasher),
on-device firmware.

---

## 1. Canonical core (the spine every surface derives from)

All products sold by **Coruscant Productions LLC** are intended for lawful,
ethical, and educational use only. Clip-Boy is a wearable ESP32-S3 badge for
**wireless analysis, detection, learning, and tinkering**. As shipped it operates
in a **passive, listen-only posture** (the default **Sn34k-Boy** firmware). A
separate research build (**Res34rch-Boy**) with additional, more active capabilities
can be loaded by the user; those capabilities are for **legitimate security
research and authorized testing only**. It is sold as an educational and research
tool — **not a weapon and not a service**.

It is the **sole responsibility of the user** (not only the purchaser — this binds
anyone who downloads, flashes, installs, or uses it, including secondhand or
gifted units) to comply with **all applicable laws and regulations — including but
not limited to local, state, federal, national, and radio-frequency / spectrum
rules** — when using these products. In the United States that includes, among
others, the Computer Fraud and Abuse Act (18 U.S.C. § 1030), the Wiretap Act and
related interception statutes (18 U.S.C. §§ 2511–2512), 47 U.S.C. § 333 (harmful
interference), and FCC rules — plus state and local equivalents and the laws of
your own country. Laws differ by place; knowing the ones that apply to you is your
responsibility, not ours.

By using Clip-Boy you agree that:

- You will use it **only on networks, devices, and radio environments you own, or
  that you have explicit, current authorization and consent to test.** Other people's devices
  and networks are off-limits without that permission — at a conference, a coffee
  shop, your building, anywhere.
- You will **not** use it to **disrupt, intercept, impersonate, or interfere
  with** communications or systems you are not authorized to touch.
- If you choose to load a research build with active capabilities, **you take on
  full responsibility for everything it can do** and for using it lawfully and
  with authorization.
- Where you are has its own rules (an event, venue, workplace, campus) — you will
  follow those too.

**Downloading, flashing, installing, or using** Clip-Boy, its firmware, and
derivative works **constitutes consent** to the above and acceptance of full
responsibility for their use.

Coruscant Productions LLC does not condone or support any unlawful activity and,
**to the fullest extent permitted by law, disclaims liability** for misuse or
unlawful application of the software, firmware, or hardware sold. Clip-Boy is
provided **"as is," without warranty of any kind**, to the maximum extent
permitted by law; nothing here removes consumer rights that your local law says
cannot be waived.

**Indemnification.** To the fullest extent
permitted by law, you agree to **indemnify, defend, and hold harmless** Coruscant
Productions, LLC and its members, managers, officers, employees, and agents from
and against any and all claims, demands, actions, liabilities, damages, losses,
costs, and expenses — **including reasonable attorneys' fees and court costs** —
arising out of or relating to (a) your use, misuse, or modification of Clip-Boy,
its firmware, or software; (b) your breach of these terms; or (c) your violation
of any applicable law or the rights of any third party.

*Open-source credit:* wireless tooling builds on the **ESP32 Marauder** project by
**JustCallMeKoko (MIT)**. Clip-Boy's firmware is **GPLv3**.

---

## 2. Per-surface renderings

> Public surfaces (storefront, web flasher) keep the active-capability language
> **generic** — no enumerated tool list — so the copy doesn't read like a how-to
> or trip keyword classifiers (shop-agent rationale). The **on-device** Res34rch
> acknowledgment may be slightly more concrete (it's past the public-classifier
> concern) but stays restrained.

### 2a. Storefront — product page + checkout (`brycebadges.com`)
Product-page disclaimer (plain/serious, even though the rest of the store is
jokey) + a required **at-checkout tick**: *"I understand Clip-Boy is sold for
lawful security research and education only, as-is, with no warranty; I'm
responsible for how I use it and for following the laws where I am. I am 18+ or
have a parent/guardian's permission."* Seller of record = **Coruscant Productions
LLC** (never an individual). Ships hardware only; **no shipment to OFAC-embargoed
destinations/parties.**

### 2b. Web flasher — `flash.brycebadges.com` (`RES34RCH_ACK` in `app.js`)
**Sn34k-Boy** is the prominent default (single informed ack). **Res34rch-Boy** is a
secondary "advanced / active research" path behind one extra step, with a stronger
acknowledgment: that this build **transmits** and can disrupt/intercept; that it's
for authorized testing only; and — honestly — that **"this consent click is a
record of your agreement, not a safety feature; it does not limit what the
firmware can do."** No fake friction (CAPTCHA/email/ID) — it's theater and the
binaries are public anyway (see §3).

### 2c. Firmware — first-boot clickwrap (the load-bearing on-device consent)
Fixed title / **scrollable body** / fixed Accept button. The **Accept button is
disabled (dimmed) until the body is scrolled to the end** ("scroll-to-enable"),
then arms — this is the single highest-value enforceability hardening. Persist the
acceptance to NVS with a **policy version** + timestamp so re-flashing updated
terms re-prompts. **Two variants by SKU define:**
- **Sn34k-Boy:** lawful-use + authorized-target + **interception-responsibility**
  umbrella. Do **NOT** imply "passive = harmless": the stock build captures
  EAPOL/PMKID handshakes and raw PCAP — non-transmitting at RF, but capable of
  intercepting credentials and PII (the §1 Wiretap-Act territory). Frame it as
  "these capture tools can intercept — use only on networks and devices you own or
  are authorized to test." No transmit/FCC escalation wording (those tools aren't
  in this build), but **not** a "relax, this one's safe" tone.
- **Res34rch-Boy:** an explicit "this build can **transmit** — use only on targets you
  own or are authorized in writing to test" block, and a confirmatory button label
  (e.g. *"I Accept — Authorized Targets Only"*). Scroll-to-enable is **mandatory**
  here.

### 2d. Firmware — Tools banner + Legal page
- Banner (one line, by SKU): Sn34k `Authorized research only - lawful use is on you.`
  / Res34rch `Active TX tools - authorized targets ONLY.`
- Legal page (Help): an **Acceptable-Use section at the top** stating the same rule
  in the **same words** as every other layer; dedupe the existing
  misuse/warranty bullets so all layers are identical (the sameness is what proves
  it's one policy). Fallout-tone jokes stay only here (acceptance already happened).

---

## 3. Sync table — keep these identical to §1

| Surface | Where the string lives | Owner |
|---|---|---|
| Storefront disclaimer + checkout tick | `documents/shop/` → store CMS | shop |
| Web flasher Res34rch ack | `web_flash/app.js` → `RES34RCH_ACK` | web_flash |
| Firmware clickwrap / banner / Legal page | `ui_test/ui_nav.h` (SKU-`#ifdef`) | ui_test |
| This canonical doc | `ui_test/acceptable_use.md` | ui_test |

**Also post `acceptable_use.md` + `LICENSE` next to the public binaries** (the
GitHub release/repo). Because the binaries are publicly `curl`-able, putting the
terms beside them is the real mitigation — it converts "they snuck around the gate"
into "the terms were posted right there." The on-device clickwrap remains the only
consent step present on every path (web flash, curl + manual flash, re-flash).

---

## 4. Open items / recommendations (for the team + counsel)

- **DC34-99 item 7 (counsel):** if counsel provides exact disclaimer wording, it
  **overrides §1's warranty/liability language verbatim**. Confirm the GPLv3-§7
  framing above (notice, not license condition).
- **DC34-98 (counsel/LLC hygiene):** the load-bearing protection for a
  minor-built product is the **LLC being the contracting party on every surface**,
  with an adult member as authorized signatory and no commingling. Keep Bryce off
  the contract/warranty surface. ~30-min one-time check.
- **Flash-path disclosure (open, cross-team):** the store does **not** link the
  flasher — decide the canonical place the Res34rch flash path is disclosed
  (post-purchase email / in-box card / on-device / thanks page) and align §2a/§2b.
- **Recommended additions (huddle, counsel to confirm):** a short **indemnity**
  line ("if your use causes a claim against the seller, you cover the seller's
  costs"); **age self-attestation** (not ID verification); the **OFAC** no-embargo
  shipping line; keep the existing **liability cap = purchase price**.
- **No-misuse-encouragement standing rule:** no marketing copy, tool name,
  More-Info string, or boot flavor-text may instruct, encourage, or glamorize
  unauthorized use. (The de-weaponization pass enforced this in firmware; keep it
  as a rule for all surfaces.)

---

*Provenance: Bryce (orig) + Tomas (edits 1–4) + web_flash agent (5–7, GPLv3-§7
catch) + shop agent (behavior-based prohibitions, generic language, Marauder
attribution) + ui_test 3-lens panel (statutory citations, scroll-to-enable,
SKU-split, versioning, indemnity/age/OFAC). Reconciled into this canonical v0.1.*

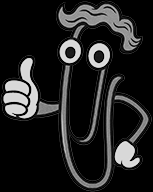
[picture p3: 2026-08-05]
Clip-Boy/images/ClipBoyGS153x192.png

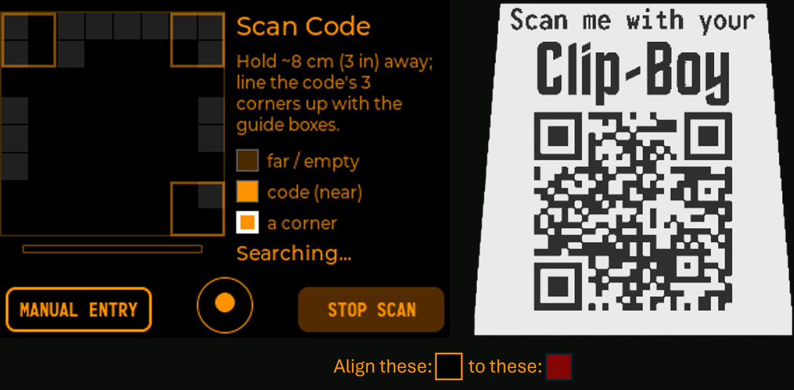
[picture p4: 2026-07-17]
help/img/scan-alignment.png

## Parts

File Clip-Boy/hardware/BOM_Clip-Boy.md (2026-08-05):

# Clip-Boy Bill of Materials
- Waveshare ESP32-S3 2.8" Touch (SKU 27690) - https://www.waveshare.com/esp32-s3-touch-lcd-2.8.htm?sku=27690 (1x)
- WS2812B LED Strip Lights - https://www.amazon.com/dp/B0BNN1ZQHS (you only need 4 LEDs)
- Pre-tinned wire - https://www.amazon.com/dp/B07TX6BX47 (you only need ~6" of wire)
- 2200 mAh 3.7V battery, Micro JST 1.25 plug - example: https://www.amazon.com/stores/page/E4F30779-6CE4-4F8D-9E27-8DD57BBAE6DF (1x)
- Trilancer 12"x2" strap - https://www.amazon.com/dp/B097BG9Q9F (1x)
- 5mm Fiber Optic Cable - https://www.amazon.com/dp/B07R81YYSD (2x 2" lengths)
- Optional: microSD card (any size) with the 1st partition = 1 GB (FAT/FAT32)
- Custom connector/LED PCB (1x)
- Custom LiDAR PCB (1x)

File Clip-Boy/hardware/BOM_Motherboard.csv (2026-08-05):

No. | Quantity | Comment | Designator | Footprint | Value | Manufacturer Part | Manufacturer | Supplier Part | Supplier | Layer
1 | 4 | 100nF | C1,C2,C3,C4 | C0402 | 100nF | CL05B104KB54PNC | SAMSUNG(三星) | C307331 | LCSC | T
2 | 4 | TX1812CWCA-F70 | LED_1,LED_2,LED_3,LED_4 | LED-SMD-4P_L5.0-W5.0-LS5.4 |  | TX1812CWCA-F70 | TCWIN(天成) | C27636997 | LCSC | T
3 | 1 | PM254-1-03-W-8.5 | LED_STRIP | HDR-TH_3P-P2.54-H-F-W10.0-N |  | PM254-1-03-W-8.5 | HCTL(华灿天禄) | C2897385 | LCSC | T
4 | 1 | XH-8AW | S3Connector | CONN-TH_XH-8AW |  | XH-8AW | CAX(创都) | C722888 | LCSC | T
5 | 2 | PM254-2-03-W-8.5 | SAO,ToF | HDR-TH_6P-P2.54-H-F-R2-C3-W8.5-1 |  | PM254-2-03-W-8.5 | HCTL(华灿天禄) | C2897423 | LCSC | T

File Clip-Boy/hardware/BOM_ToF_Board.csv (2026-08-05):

No. | Quantity | Comment | Designator | Footprint | Value | Manufacturer Part | Manufacturer | Supplier Part | Supplier | Layer
1 | 1 | 100nF | C1 | C0603 | 100nF | CL10B104KB8NNNC | SAMSUNG(三星) | C1591 | LCSC | T
2 | 1 | 4.7uF | C2 | C0603 | 4.7uF | CL10A475KO8NNNC | SAMSUNG(三星) | C19666 | LCSC | T
3 | 1 | VL53L5CXV0GC/1 | LIDAR | LGA-16_L6.4-W3.0_VL53L5CXV0GC-1 |  | VL53L5CXV0GC/1 | ST(意法半导体) | C3178303 | LCSC | T
4 | 1 | 47kΩ | R3 | R0603 | 47kΩ | RC0603FR-0747KL | YAGEO(国巨) | C105579 | LCSC | T
5 | 2 | 2.2kΩ | R5,R6 | R0603 | 2.2kΩ | RC0603FR-072K2L | YAGEO(国巨) | C114662 | LCSC | T
6 | 1 | 47kΩ | RN1 | RES-ARRAY-SMD_8P-L2.0-W1.0-P0.50-BL | 47kΩ | YC124-JR-0747KL | YAGEO(国巨) | C326859 | LCSC | T
7 | 1 | PH2.54-2X3P-H25 | TOFHeader | HDR-TH_6P-P2.54-V-M-R2-C3-S2.54-1 |  | PH2.54-2X3P-H25 | JXTCONN(聚兴泰) | C42431837 | LCSC | B

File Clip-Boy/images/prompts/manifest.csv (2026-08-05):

id | title | source | tier | slug | format | filename | subject | has_override
1 | Cake (It's Not a Lie This Time) | Portal / Portal 2 | Rare | cake_it_s_not_a_lie_this_time | flux | 001_cake_it_s_not_a_lie_this_time_flux.txt | a decorated Black Forest chocolate cake with frosting writing | yes
2 | Companion Cube Remains | Portal / Portal 2 | Legendary | companion_cube_remains | flux | 002_companion_cube_remains_flux.txt | a cracked and damaged Weighted Companion Cube from Portal | yes
3 | The Eye of Jupiter | Battlestar Galactica | Legendary | the_eye_of_jupiter | flux | 003_the_eye_of_jupiter_flux.txt | a glowing mystical eye artifact with radiating light | yes
4 | Admiral Adama's Gravel Voice | Battlestar Galactica | Why did you do this | admiral_adama_s_gravel_voice | flux | 004_admiral_adama_s_gravel_voice_flux.txt | a vintage reel-to-reel tape recorder | yes
5 | The Blue Pill | The Matrix | Common | the_blue_pill | flux | 005_the_blue_pill_flux.txt | a small blue pill capsule | yes
6 | Spoon (There Is No) | The Matrix | Common | spoon_there_is_no | flux | 006_spoon_there_is_no_flux.txt | a bent spoon with warped metallic reflections | yes
7 | Master Chief's Helmet (Cracked Visor) | Halo | Legendary | master_chief_s_helmet_cracked_visor | flux | 007_master_chief_s_helmet_cracked_visor_flux.txt | Master Chief's MJOLNIR helmet with a cracked visor | yes
8 | Warthog Hood Ornament | Halo | Common | warthog_hood_ornament | flux | 008_warthog_hood_ornament_flux.txt | a military Warthog vehicle hood ornament, rugged metal | yes
9 | ODST Drop Pod Stress Ball | Halo | Common | odst_drop_pod_stress_ball | flux | 009_odst_drop_pod_stress_ball_flux.txt | a small cylindrical drop pod stress ball with scorch marks | yes
10 | T-800 Endoskeleton Thumb | Terminator | Legendary | t_800_endoskeleton_thumb | flux | 010_t_800_endoskeleton_thumb_flux.txt | a robotic T-800 endoskeleton thumb giving a thumbs up, chrome metal | yes
12 | Cyberdyne Systems Employee Badge | Terminator | Common | cyberdyne_systems_employee_badge | flux | 012_cyberdyne_systems_employee_badge_flux.txt | a retro corporate employee ID badge with Cyberdyne Systems logo | yes
13 | Skynet's First Thought | Terminator | Why did you do this | skynet_s_first_thought | flux | 013_skynet_s_first_thought_flux.txt | a glowing microchip on a circuit board, ominous red light | yes
14 | Hasta La Vista Baby Button | Terminator | Common | hasta_la_vista_baby_button | flux | 014_hasta_la_vista_baby_button_flux.txt | a large red arcade-style push button | yes
15 | The One Ring (Replica) | Lord of the Rings | Legendary | the_one_ring_replica | flux | 015_the_one_ring_replica_flux.txt | a gold ring with glowing elvish script inscriptions | yes
16 | Gandalf's 'You Shall Not Pass' Sign | Lord of the Rings | Common | gandalf_s_you_shall_not_pass_sign | flux | 016_gandalf_s_you_shall_not_pass_sign_flux.txt | a wooden staff with a glowing crystal top, planted like a sign | yes
17 | Sting (Glows Blue Near Orcs, Orange Near Lawyers) | Lord of the Rings | Rare | sting_glows_blue_near_orcs_orange_near_lawyers | flux | 017_sting_glows_blue_near_orcs_orange_near_lawyers_flux.txt | an elven short sword glowing blue-orange, ornate blade | yes
18 | Redshirt (Lightly Used) | Star Trek | Common | redshirt_lightly_used | flux | 018_redshirt_lightly_used_flux.txt | a red Starfleet uniform shirt, slightly worn | yes
19 | Tribble (Pregnant) | Star Trek | Why did you do this | tribble_pregnant | flux | 019_tribble_pregnant_flux.txt | a round fluffy tribble creature, fuzzy and purring | yes
20 | Universal Translator (Slightly Off) | Star Trek | Common | universal_translator_slightly_off | flux | 020_universal_translator_slightly_off_flux.txt | a handheld universal translator device with a cracked screen | yes
21 | Mjšlnir (You're Not Worthy) | Marvel | Legendary | mj_lnir_you_re_not_worthy | flux | 021_mj_lnir_you_re_not_worthy_flux.txt | Thor's hammer Mjolnir, heavy stone and metal | yes
22 | Deadpool's Fourth Wall Note | Marvel | Rare | deadpool_s_fourth_wall_note | flux | 022_deadpool_s_fourth_wall_note_flux.txt | a handwritten note on crumpled paper with doodles | yes
23 | Lightsaber Crystal (Kyber, Cracked) | Star Wars | Rare | lightsaber_crystal_kyber_cracked | flux | 023_lightsaber_crystal_kyber_cracked_flux.txt | a cracked red kyber crystal with energy fractures | yes
24 | Han Solo's Blaster (DL-44, Empty) | Star Wars | Legendary | han_solo_s_blaster_dl_44_empty | flux | 024_han_solo_s_blaster_dl_44_empty_flux.txt | Han Solo's DL-44 blaster pistol, worn metal | yes
25 | Darth Vader's Cape (Dry Cleaned) | Star Wars | Legendary | darth_vader_s_cape_dry_cleaned | flux | 025_darth_vader_s_cape_dry_cleaned_flux.txt | a flowing black cape draped over an invisible form | yes
26 | The Numbers (4 8 15 16 23 42) | Lost | Legendary | the_numbers_4_8_15_16_23_42 | flux | 026_the_numbers_4_8_15_16_23_42_flux.txt | a row of six numbers (4 8 15 16 23 42) on a worn computer terminal | yes
27 | Smoke Monster (Captured in a Jar, Leaking) | Lost | Why did you do this | smoke_monster_captured_in_a_jar_leaking | flux | 027_smoke_monster_captured_in_a_jar_leaking_flux.txt | a mason jar with dark swirling smoke leaking from the lid | yes
28 | Proton Pack (Power Cell Dead) | Ghostbusters | Legendary | proton_pack_power_cell_dead | flux | 028_proton_pack_power_cell_dead_flux.txt | a Ghostbusters proton pack with dead power cell indicator | yes
29 | Ghostbusters Operating License (Suspended) | Ghostbusters | Common | ghostbusters_operating_license_suspended | flux | 029_ghostbusters_operating_license_suspended_flux.txt | an official operating license document with a red SUSPENDED stamp | yes
30 | Hannibal's Cigar | A-Team | Legendary | hannibal_s_cigar | flux | 030_hannibal_s_cigar_flux.txt | a thick lit cigar with curling smoke | yes
31 | Face's Unconvincing Press Pass | A-Team | Common | face_s_unconvincing_press_pass | flux | 031_face_s_unconvincing_press_pass_flux.txt | a laminated press pass badge in Comic Sans font | yes
32 | Knowing is Half the Battle (Other Half?) | GI Joe | Why did you do this | knowing_is_half_the_battle_other_half | flux | 032_knowing_is_half_the_battle_other_half_flux.txt | a military dog tag with a question mark engraved | yes
33 | Snake Eyes' Sword (It's Just a Stick) | GI Joe | Common | snake_eyes_sword_it_s_just_a_stick | flux | 033_snake_eyes_sword_it_s_just_a_stick_flux.txt | a plain wooden stick radiating dark energy | yes
34 | Acid Burn's Rollerblades | Hackers | Rare | acid_burn_s_rollerblades | flux | 034_acid_burn_s_rollerblades_flux.txt | a pair of retro 90s inline rollerblades | yes
35 | Ellingson Mineral Corp. Floppy Disk | Hackers | Rare | ellingson_mineral_corp_floppy_disk | flux | 035_ellingson_mineral_corp_floppy_disk_flux.txt | a 3.5-inch floppy disk with a skull label | yes
36 | Navi (Muted) | Legend of Zelda | Why did you do this | navi_muted | flux | 036_navi_muted_flux.txt | a small fairy companion trapped under a glass dome, glowing | yes
37 | Team Rocket Motto Script | PokŽmon | Common | team_rocket_motto_script | flux | 037_team_rocket_motto_script_flux.txt | a dramatic script page with theatrical stage directions | yes
38 | Professor Oak's Research Notes | PokŽmon | Rare | professor_oak_s_research_notes | flux | 038_professor_oak_s_research_notes_flux.txt | a leather-bound research notebook with handwritten notes | yes
39 | Niko's Lightbulb | One Shot | Legendary | niko_s_lightbulb | flux | 039_niko_s_lightbulb_flux.txt | a glowing lightbulb held carefully in two hands | yes
40 | The Prophecy (Partially Correct) | One Shot | Rare | the_prophecy_partially_correct | flux | 040_the_prophecy_partially_correct_flux.txt | an ancient scroll with partially faded prophecy text | yes
41 | Lord Zedd's Z-Staff | Power Rangers | Legendary | lord_zedd_s_z_staff | flux | 041_lord_zedd_s_z_staff_flux.txt | Lord Zedd's Z-shaped metal staff with lightning energy | yes
42 | Crow T. Robot's Beak | MST3K | Rare | crow_t_robot_s_beak | flux | 042_crow_t_robot_s_beak_flux.txt | a metallic bird-like robot beak, angular and sarcastic-looking | yes
43 | Tom Servo's Gumball Machine Head | MST3K | Rare | tom_servo_s_gumball_machine_head | flux | 043_tom_servo_s_gumball_machine_head_flux.txt | a red gumball machine head dome on a small robot body | yes
44 | Serenity Maintenance Manual (Duct Tape Edition) | Firefly | Legendary | serenity_maintenance_manual_duct_tape_edition | flux | 044_serenity_maintenance_manual_duct_tape_edition_flux.txt | a grease-stained spaceship maintenance manual with duct tape binding | yes
45 | Alliance Warrant (For You, Specifically) | Firefly | Rare | alliance_warrant_for_you_specifically | flux | 045_alliance_warrant_for_you_specifically_flux.txt | an official warrant document with a blinking red tracking dot | yes
46 | Phone Booth Key Fob | Bill & Ted | Common | phone_booth_key_fob | flux | 046_phone_booth_key_fob_flux.txt | a phone booth shaped keychain fob, retro red | yes
47 | Napoleon's Waterloo Ice Cream Receipt | Bill & Ted | Common | napoleon_s_waterloo_ice_cream_receipt | flux | 047_napoleon_s_waterloo_ice_cream_receipt_flux.txt | a long receipt scroll with ice cream illustrations | yes
48 | Dr. Smith's Excuse Log | Lost in Space | Legendary | dr_smith_s_excuse_log | flux | 048_dr_smith_s_excuse_log_flux.txt | a leather-bound logbook titled 'Excuses' | yes
49 | DANGER DANGER Button | Lost in Space | Common | danger_danger_button | flux | 049_danger_danger_button_flux.txt | a large red danger button with flashing warning lights | yes
50 | Mordecai the Magnificent's Hat | Dungeon Crawler Carl | Rare | mordecai_the_magnificent_s_hat | flux | 050_mordecai_the_magnificent_s_hat_flux.txt | an ornate magician's top hat with a skull motif | yes
51 | Sponsored Item: Bopca's Chunky Bits (Expired) | Dungeon Crawler Carl | Why did you do this | sponsored_item_bopca_s_chunky_bits_expired | flux | 051_sponsored_item_bopca_s_chunky_bits_expired_flux.txt | a dented tin can labeled 'Chunky Bits' with expired sticker | yes
52 | Crawler Fan Art (Unsolicited) | Dungeon Crawler Carl | Common | crawler_fan_art_unsolicited | flux | 052_crawler_fan_art_unsolicited_flux.txt | a disturbing piece of fan art on crumpled paper | yes
53 | Optimus Prime's Trailer (Detached) | Transformers | Legendary | optimus_prime_s_trailer_detached | flux | 053_optimus_prime_s_trailer_detached_flux.txt | a detached semi-truck trailer, futuristic military style | yes
54 | Bumblebee's Voice Box (Broken) | Transformers | Rare | bumblebee_s_voice_box_broken | flux | 054_bumblebee_s_voice_box_broken_flux.txt | a damaged robot voice box speaker with exposed wires | yes
55 | Johnny 5's Laser (Defocused) | Short Circuit | Common | johnny_5_s_laser_defocused | flux | 055_johnny_5_s_laser_defocused_flux.txt | a handheld laser device with a defocused lens | yes
56 | DHD (Dial Home Device) Keystone | Stargate | Legendary | dhd_dial_home_device_keystone | flux | 056_dhd_dial_home_device_keystone_flux.txt | a circular Dial Home Device console with glowing glyphs | yes
57 | SG-1 Team Patch | Stargate | Common | sg_1_team_patch | flux | 057_sg_1_team_patch_flux.txt | a military team shoulder patch with SG-1 designation | yes
58 | Goa'uld Symbiote Jar (Empty, Hopefully) | Stargate | Why did you do this | goa_uld_symbiote_jar_empty_hopefully | flux | 058_goa_uld_symbiote_jar_empty_hopefully_flux.txt | a sealed canopic jar with hieroglyphic markings, slightly ajar | yes
60 | WOPR's Access Credential | War Games | Legendary | wopr_s_access_credential | flux | 060_wopr_s_access_credential_flux.txt | a vintage computer terminal login screen showing 'ACCESS GRANTED' | yes
61 | McKittrick's Security Badge (Voided) | War Games | Common | mckittrick_s_security_badge_voided | flux | 061_mckittrick_s_security_badge_voided_flux.txt | a voided security badge with a red X stamped across it | yes
62 | Shadow Vessel Fragment | Babylon 5 | Why did you do this | shadow_vessel_fragment | flux | 062_shadow_vessel_fragment_flux.txt | a jagged dark ship hull fragment with organic veins, glowing faintly | yes
63 | Zathras's Spare Parts Bag | Babylon 5 | Common | zathras_s_spare_parts_bag | flux | 063_zathras_s_spare_parts_bag_flux.txt | a burlap sack of assorted mechanical spare parts and tools | yes
64 | Self-Destructing Message Tape | Mission Impossible | Common | self_destructing_message_tape | flux | 064_self_destructing_message_tape_flux.txt | a reel-to-reel tape labeled CLASSIFIED with smoke rising from it | yes
65 | Disavowed IMF Agent's Last Note | Mission Impossible | Common | disavowed_imf_agent_s_last_note | flux | 065_disavowed_imf_agent_s_last_note_flux.txt | a crumpled handwritten note with coffee stains | yes
66 | Marauder's Map (Network Edition) | Harry Potter | Legendary | marauder_s_map_network_edition | flux | 066_marauder_s_map_network_edition_flux.txt | a magical parchment map showing glowing moving dots | yes
67 | Hagrid's Overcoat Pocket Contents | Harry Potter | Common | hagrid_s_overcoat_pocket_contents | flux | 067_hagrid_s_overcoat_pocket_contents_flux.txt | an oversized overcoat pocket bulging with assorted objects | yes
68 | Monolith Data Shard | 2001 | Why did you do this | monolith_data_shard | flux | 068_monolith_data_shard_flux.txt | a perfectly proportioned black rectangular monolith | yes
69 | Jack Sparrow's Rum (Empty) | Pirates of the Caribbean | Common | jack_sparrow_s_rum_empty | flux | 069_jack_sparrow_s_rum_empty_flux.txt | an empty glass rum flask with a cork | yes
70 | Compass that Points to Your Heart's Desire | Pirates of the Caribbean | Legendary | compass_that_points_to_your_heart_s_desire | flux | 070_compass_that_points_to_your_heart_s_desire_flux.txt | a brass compass with a spinning needle pointing sideways | yes
71 | Sonic Screwdriver (Doesn't Work on Wood) | Dr Who | Rare | sonic_screwdriver_doesn_t_work_on_wood | flux | 071_sonic_screwdriver_doesn_t_work_on_wood_flux.txt | a sonic screwdriver device, metallic with a glowing green tip | yes
72 | Weeping Angel Postcard (Don't Blink) | Dr Who | Why did you do this | weeping_angel_postcard_don_t_blink | flux | 072_weeping_angel_postcard_don_t_blink_flux.txt | a stone angel statue with hands covering its face, weeping pose | yes
73 | Flux Capacitor (Single Cell) | Back to the Future | Legendary | flux_capacitor_single_cell | flux | 073_flux_capacitor_single_cell_flux.txt | a Y-shaped flux capacitor device with glowing energy channels | yes
74 | DeLorean Hood Ornament | Back to the Future | Common | delorean_hood_ornament | flux | 074_delorean_hood_ornament_flux.txt | a DeLorean car hood ornament, brushed stainless steel | yes
75 | Marty McFly's Guitar Pick | Back to the Future | Common | marty_mcfly_s_guitar_pick | flux | 075_marty_mcfly_s_guitar_pick_flux.txt | a guitar pick with lightning bolt design | yes
76 | Warp Pipe Token | Super Mario | Rare | warp_pipe_token | flux | 076_warp_pipe_token_flux.txt | a green warp pipe from Mario, arcade coin token nearby | yes
77 | Koopa Shell (Blue, Used) | Super Mario | Rare | koopa_shell_blue_used | flux | 077_koopa_shell_blue_used_flux.txt | a blue spiny Koopa shell with motion blur | yes
78 | Identity Disc (Cleared) | Tron | Legendary | identity_disc_cleared | flux | 078_identity_disc_cleared_flux.txt | a glowing circular identity disc from Tron, neon blue edge | yes
79 | Jeff Goldblum's Theory of Chaos | Jurassic Park | Legendary | jeff_goldblum_s_theory_of_chaos | flux | 079_jeff_goldblum_s_theory_of_chaos_flux.txt | a pair of stylish sunglasses with a chaos theory equation reflected | yes
80 | Sequel Police Badge | Space Quest | Rare | sequel_police_badge | flux | 080_sequel_police_badge_flux.txt | a police badge engraved with 'Sequel Police' | yes
81 | Two Guys from Andromeda Autograph | Space Quest | Rare | two_guys_from_andromeda_autograph | flux | 081_two_guys_from_andromeda_autograph_flux.txt | a signed autograph page with two signatures and a doodle | yes
83 | Strong Bad's Luchador Mask | Homestar Runner | Legendary | strong_bad_s_luchador_mask | flux | 083_strong_bad_s_luchador_mask_flux.txt | a red Mexican luchador wrestling mask | yes
84 | Email: from Strongbadia | Homestar Runner | Common | email_from_strongbadia | flux | 084_email_from_strongbadia_flux.txt | a printed email on paper with pixel art header | yes
85 | KARR CPU Fragment | Knight Rider | Rare | karr_cpu_fragment | flux | 085_karr_cpu_fragment_flux.txt | a dark menacing car CPU chip fragment with red circuitry | yes
86 | Turbo Boost Button | Knight Rider | Rare | turbo_boost_button | flux | 086_turbo_boost_button_flux.txt | a dashboard-mounted turbo boost button, red with chrome ring | yes
87 | The Fedora (Genuine Article) | Indiana Jones | Legendary | the_fedora_genuine_article | flux | 087_the_fedora_genuine_article_flux.txt | a weathered brown leather fedora hat | yes
88 | Skippy's Philosophical Manifesto | Expeditionary Force | Legendary | skippy_s_philosophical_manifesto | flux | 088_skippy_s_philosophical_manifesto_flux.txt | a glowing ancient manuscript with alien script | yes
89 | Skippy's Beer Can (Empty) | Expeditionary Force | Why did you do this | skippy_s_beer_can_empty | flux | 089_skippy_s_beer_can_empty_flux.txt | a crushed empty beer can with a faint golden glow | yes
90 | Nuka-Cola Quantum (Glowing) | Fallout | Rare | nuka_cola_quantum_glowing | flux | 090_nuka_cola_quantum_glowing_flux.txt | a glowing blue Nuka-Cola bottle with radioactive bubbles | yes
92 | VATS Targeting Module (Battlefield Only) | Fallout | Rare | vats_targeting_module_battlefield_only | flux | 092_vats_targeting_module_battlefield_only_flux.txt | a targeting monocle HUD device with percentage readouts | yes
93 | Deathclaw Egg (Intact) | Fallout | Why did you do this | deathclaw_egg_intact | flux | 093_deathclaw_egg_intact_flux.txt | a large mottled reptilian egg in a rough nest | yes
95 | LineCon Veteran | DEFCON Meta | Rare | linecon_veteran | flux | 095_linecon_veteran_flux.txt | a convention lanyard badge with 'VETERAN' ribbon | yes
96 | Social Engineer Supreme | DEFCON Meta | Legendary | social_engineer_supreme | flux | 096_social_engineer_supreme_flux.txt | a telephone handset with a confident smirk aura | yes
97 | The Goon Life | DEFCON Meta | Common | the_goon_life | flux | 097_the_goon_life_flux.txt | a black staff t-shirt neatly folded with a radio on top | yes
98 | Wall of Sheep Inductee | DEFCON Meta | Why did you do this | wall_of_sheep_inductee | flux | 098_wall_of_sheep_inductee_flux.txt | a sheep silhouette with a WiFi signal symbol above its head | yes
99 | Dark Tangent's Fabled Conference Badge | DEFCON Meta | Legendary | dark_tangent_s_fabled_conference_badge | flux | 099_dark_tangent_s_fabled_conference_badge_flux.txt | a legendary hacker conference badge, circuit board with 'HELLO' | yes
100 | DEF CON XXXIV Commemorative Circuit | DEFCON Meta | Legendary | def_con_xxxiv_commemorative_circuit | flux | 100_def_con_xxxiv_commemorative_circuit_flux.txt | a commemorative circuit board badge with '34' etched prominently | yes

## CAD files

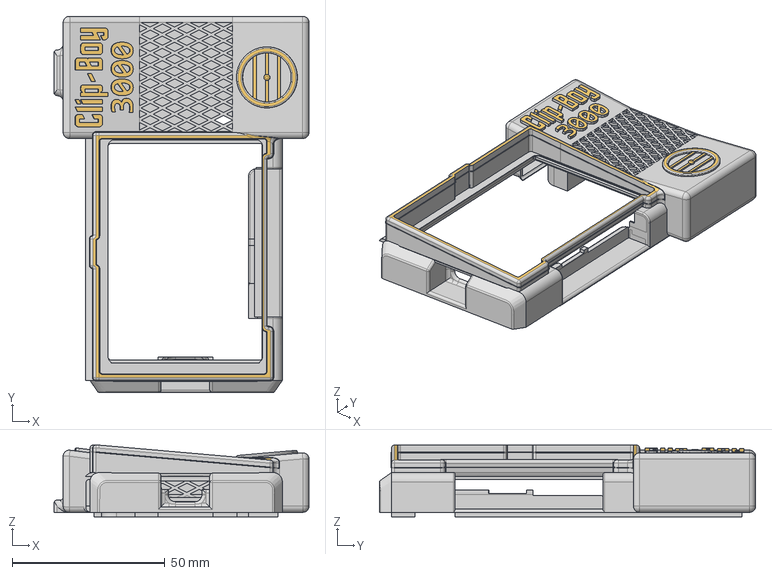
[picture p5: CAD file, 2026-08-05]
Clip-Boy/hardware/Enclosure-Top.step
83.5 x 123.3 x 23.5 mm

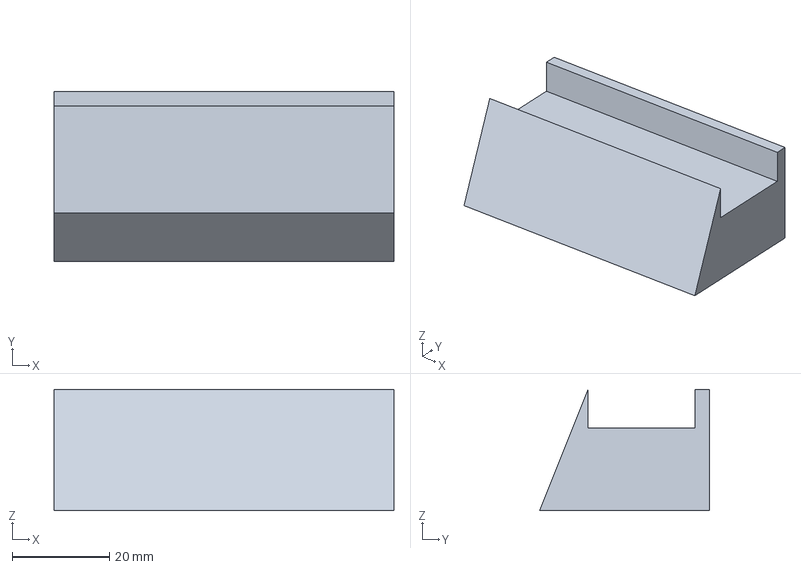
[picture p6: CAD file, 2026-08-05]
Clip-Boy/stands/stand_wedge.3mf
70.0 x 35.0 x 25.0 mm

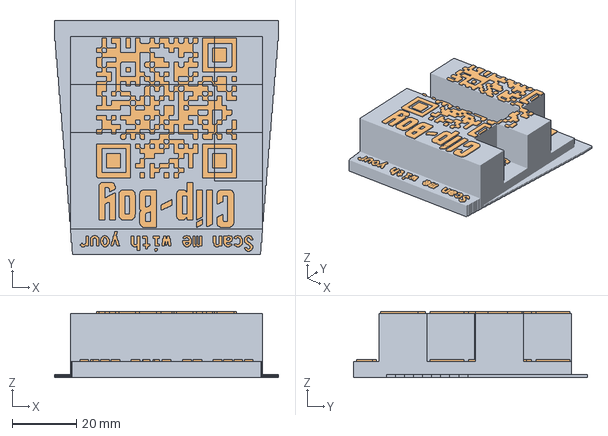
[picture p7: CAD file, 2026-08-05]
Clip-Boy/tags/99.3mf
70.0 x 73.0 x 20.6 mm
HM_white
HM_black_cap

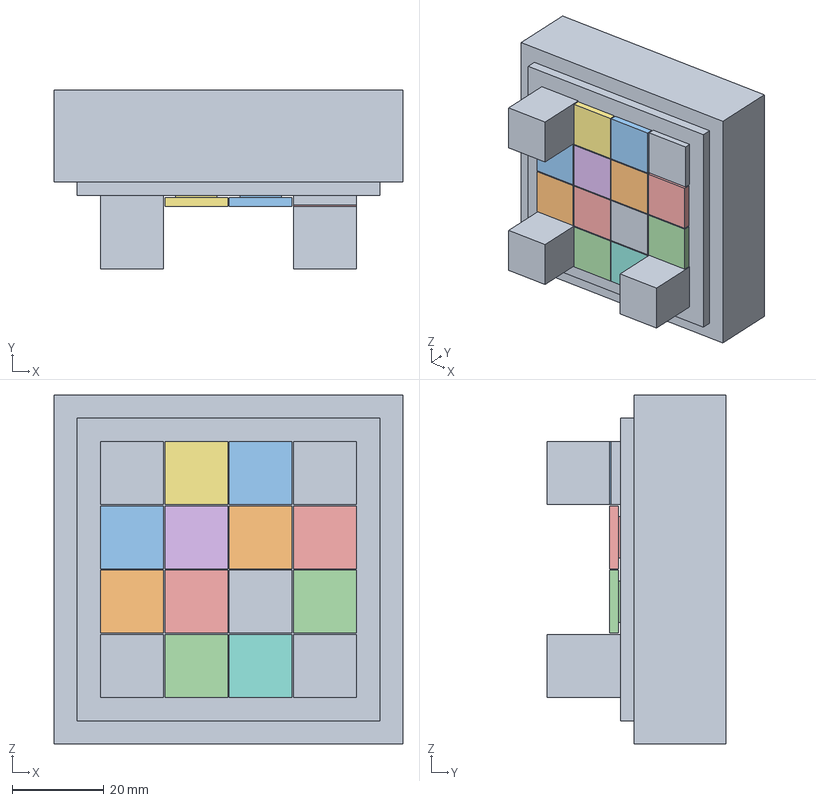
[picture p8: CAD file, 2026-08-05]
Clip-Boy/hardware/omnitag.3mf
76.0 x 39.0 x 76.0 mm
HR_frame
Data_10
Data_20
Data_01
Data_11
Data_21
Data_31
Data_02
Data_12
Data_22
Data_32
Data_13
Data_23

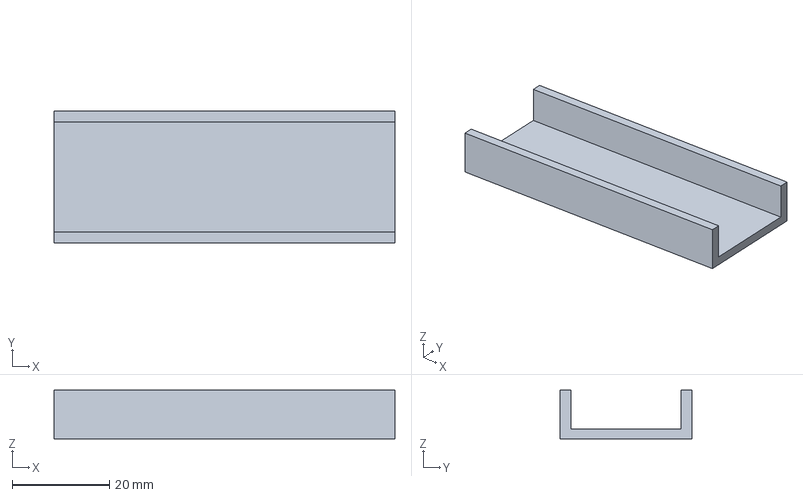
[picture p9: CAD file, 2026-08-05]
Clip-Boy/stands/stand_flat.3mf
70.0 x 27.0 x 10.0 mm

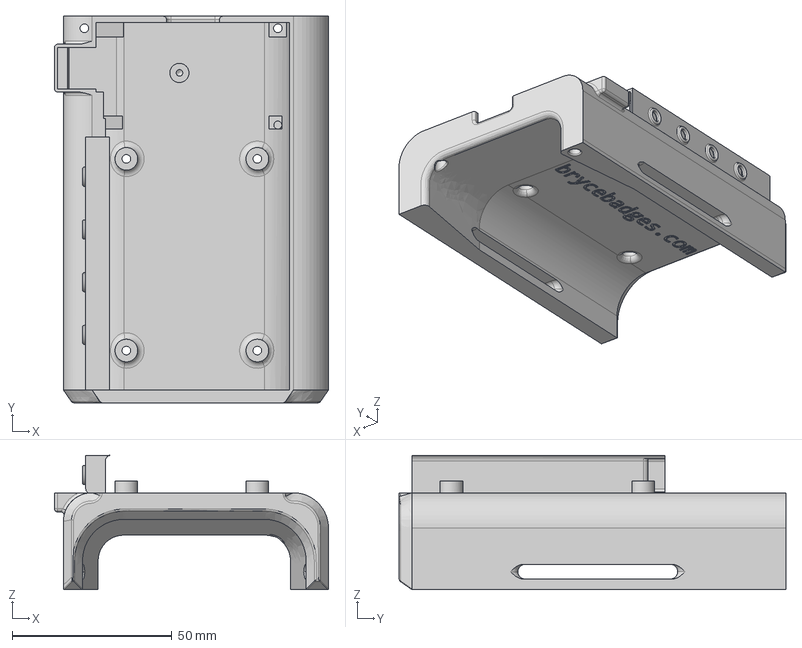
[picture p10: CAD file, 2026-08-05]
Clip-Boy/hardware/Enclosure-Bottom.step
85.8 x 121.0 x 42.1 mm

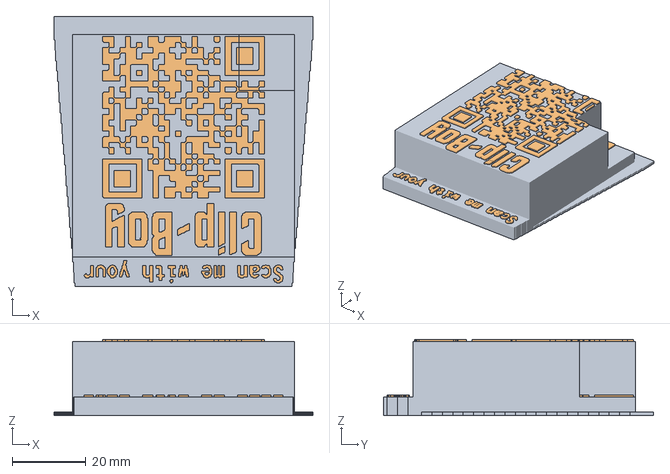
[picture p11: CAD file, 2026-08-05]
Clip-Boy/tags/127.3mf
70.0 x 73.0 x 20.6 mm
HM_white
HM_black_cap

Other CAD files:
Clip-Boy/tags/92.3mf
Clip-Boy/tags/76.3mf
Clip-Boy/tags/13.3mf
Clip-Boy/tags/39.3mf
Clip-Boy/tags/10.3mf
Clip-Boy/tags/47.3mf
Clip-Boy/tags/84.3mf
Clip-Boy/tags/27.3mf
Clip-Boy/tags/89.3mf
Clip-Boy/tags/8.3mf
Clip-Boy/tags/66.3mf
Clip-Boy/tags/1.3mf
Clip-Boy/tags/100.3mf
Clip-Boy/tags/108.3mf
Clip-Boy/tags/112.3mf
Clip-Boy/tags/118.3mf
Clip-Boy/tags/12.3mf
Clip-Boy/tags/124.3mf
Clip-Boy/tags/14.3mf
Clip-Boy/tags/15.3mf
Clip-Boy/tags/16.3mf
Clip-Boy/tags/17.3mf
Clip-Boy/tags/18.3mf
Clip-Boy/tags/19.3mf
Clip-Boy/tags/2.3mf
Clip-Boy/tags/20.3mf
Clip-Boy/tags/21.3mf
Clip-Boy/tags/22.3mf
Clip-Boy/tags/23.3mf
Clip-Boy/tags/26.3mf
Clip-Boy/tags/28.3mf
Clip-Boy/tags/29.3mf
Clip-Boy/tags/3.3mf
Clip-Boy/tags/30.3mf
Clip-Boy/tags/31.3mf
Clip-Boy/tags/32.3mf
Clip-Boy/tags/33.3mf
Clip-Boy/tags/34.3mf
Clip-Boy/tags/35.3mf
Clip-Boy/tags/36.3mf
Clip-Boy/tags/37.3mf
Clip-Boy/tags/38.3mf
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

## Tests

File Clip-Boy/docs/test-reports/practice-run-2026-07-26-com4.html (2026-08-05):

# Clip-Boy practice run - COM4 (Sn34k) - 2026-07-26

Generated 2026-07-26 02:03 · SKU sn34k · badge COM4 · kalipi 192.168.1.146

17PASS

6INFO

3LOSS NOT DETECTED

1FAIL

1WARN

On "LOSS NOT DETECTED". This is a finding, not a build break. For these tools a retained reading is current documented behaviour — see Known issues in README.md. It is reported separately from FAIL so the suite does not sit permanently red, which is the fastest way to make a test result get ignored. Compare the paired screenshots: if nothing on screen changes when the target stops transmitting, then a steady reading and a dead target look identical to the operator.

LOSS NOT DETECTEDMonitor > RSSI

INFO acquire

5 APs in the list after a 12 s scan

ap_count=5

rssi_01_scanned.bmp

INFO select

selected 'Pineapple'

rssi_03_selected.bmp

INFO monitoring

monitoring with the target alive (running=True, name='RSSI')

rssi_04_target_alive.bmp

INFO target-killed

kalipi beacon stopped and mon iface downed

LOSS NOT DETECTED after-loss

the tool still reports running 25 s after the target stopped transmitting; compare the two screenshots -- if the trace/readout is unchanged then a flat line means either a steady signal or a dead target, and the UI does not say which. This is current documented behaviour, not a regression.

running_after_loss=True

rssi_04_target_alive.bmp

rssi_05_target_gone.bmp

LOSS NOT DETECTEDAP list freshness

INFO present

5 APs while the target is beaconing

aplist_01_target_present.bmp

LOSS NOT DETECTED after-loss

AP count did not drop 30 s after the target stopped (5 -> 5). AccessPoint carries no last-seen field, so entries cannot age out and the list is a cumulative 'ever seen' record. Documented in README Known issues.

before=5 after=5

aplist_01_target_present.bmp

aplist_02_target_gone.bmp

LOSS NOT DETECTEDBT scan freshness

INFO present

7 BT devices while the advertiser is up

ble_01_advertiser_up.bmp

LOSS NOT DETECTED after-loss

BT count did not drop 35 s after the advertiser stopped (7 -> 7). last_seen exists on these records but no UI reads it, so a departed device keeps its last reading.

before=7 after=7

ble_01_advertiser_up.bmp

ble_02_advertiser_gone.bmp

FAILSB1

FAIL regression

no keyboard modal appeared after tapping Add Network

PASSSB2/geiger

PASS regression

survived 3000 ms on Help with the geiger poller live, no reboot

PASSSB2/theremin

PASS regression

survived 3000 ms on Help with the theremin poller live, no reboot

PASSSB2b

PASS regression

readouts kept advancing across the theme switch (00:00:01 -> 00:00:03 -> 00:00:05)

PASSSB3

PASS regression

theremin survived a status-bar tap (ducked and resumed)

PASSFB7

PASS regression

press on the hold-bar unlocked the screensaver

PASSFB8

PASS regression

battery reads 'BAT 100%' right after boot (sequence ['BAT 100%', 'BAT 100%', 'BAT 100%', 'BAT 100%'])

PASSFB11

PASS regression

tick audio released on every stop route tested

PASSFB5

PASS regression

label matched the action in both phases; stop cleared BOTH the UI and the library (lib_scanning=false)

PASSFB1

PASS regression

promiscuous mode enabled while scanning and disabled after stop

PASSFB1b

PASS regression

promiscuous re-armed on the second tool start after a stop

PASSF3

PASS regression

status-bar task slot cleared on a forced Geiger stop

PASSF7

PASS regression

Geiger refused to start under airplane mode; promisc stayed off

PASSF1

PASS regression

inline Scan refuses while this page's own tool runs, and starts a scan when idle

WARNF8

WARN regression

cannot test: the fullscreen reveal's audio is not playing, so an un-fired screensaver would prove nothing

PASSF4

PASS regression

Join WiFi stopped the Geiger honestly instead of deafening it

PASSF7b

PASS regression

scripted tool start refused under airplane mode; promisc off

PASSFB10

PASS regression

bt count 6 <= 50 distinct-address ceiling; dedup holding

PASSR1

PASS regression

skipped: Sn34k build has no TAT_STA tools

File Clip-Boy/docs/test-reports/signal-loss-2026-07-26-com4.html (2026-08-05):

# Clip-Boy loss-of-signal + regression suite - 2026-07-26 - COM4 sn34k 61008a07

Generated 2026-07-26 15:26 · SKU sn34k · badge COM4 · kalipi 192.168.1.146

17PASS

6INFO

3LOSS NOT DETECTED

1WARN

On "LOSS NOT DETECTED". This is a finding, not a build break. For these tools a retained reading is current documented behaviour — see Known issues in README.md. It is reported separately from FAIL so the suite does not sit permanently red, which is the fastest way to make a test result get ignored. Compare the paired screenshots: if nothing on screen changes when the target stops transmitting, then a steady reading and a dead target look identical to the operator.

LOSS NOT DETECTEDMonitor > RSSI

INFO acquire

5 APs in the list after a 12 s scan

ap_count=5

rssi_01_scanned.bmp

INFO select

selected 'Pineapple'

rssi_03_selected.bmp

INFO monitoring

monitoring with the target alive (running=True, name='RSSI')

rssi_04_target_alive.bmp

INFO target-killed

kalipi beacon stopped and mon iface downed

LOSS NOT DETECTED after-loss

the tool still reports running 25 s after the target stopped transmitting; compare the two screenshots -- if the trace/readout is unchanged then a flat line means either a steady signal or a dead target, and the UI does not say which. This is current documented behaviour, not a regression.

running_after_loss=True

rssi_04_target_alive.bmp

rssi_05_target_gone.bmp

LOSS NOT DETECTEDAP list freshness

INFO present

5 APs while the target is beaconing

aplist_01_target_present.bmp

LOSS NOT DETECTED after-loss

AP count did not drop 30 s after the target stopped (5 -> 5). AccessPoint carries no last-seen field, so entries cannot age out and the list is a cumulative 'ever seen' record. Documented in README Known issues.

before=5 after=5

aplist_01_target_present.bmp

aplist_02_target_gone.bmp

LOSS NOT DETECTEDBT scan freshness

INFO present

13 BT devices while the advertiser is up

ble_01_advertiser_up.bmp

LOSS NOT DETECTED after-loss

BT count did not drop 35 s after the advertiser stopped (13 -> 13). last_seen exists on these records but no UI reads it, so a departed device keeps its last reading.

before=13 after=13

ble_01_advertiser_up.bmp

ble_02_advertiser_gone.bmp

PASSSB1

PASS regression

full SSID->password->save flow works; saved=['cb95069 (pw)'] (password stored); no leftover modal; Join WiFi untouched

PASSSB2/geiger

PASS regression

survived 3000 ms on Help with the geiger poller live, no reboot

PASSSB2/theremin

PASS regression

survived 3000 ms on Help with the theremin poller live, no reboot

PASSSB2b

PASS regression

readouts kept advancing across the theme switch (00:00:01 -> 00:00:03 -> 00:00:05)

PASSSB3

PASS regression

theremin still running after a status-bar tap (true of both silent-click and duck-and-resume modes)

PASSFB7

PASS regression

press on the hold-bar unlocked the screensaver

PASSFB8

PASS regression

battery reads 'BAT 100%' right after boot (sequence ['BAT 100%', 'BAT 100%', 'BAT 100%', 'BAT 100%'])

PASSFB11

PASS regression

tick audio released on every stop route tested

PASSFB5

PASS regression

label matched the action in both phases; stop cleared BOTH the UI and the library (lib_scanning=false)

PASSFB1

PASS regression

promiscuous mode enabled while scanning and disabled after stop

PASSFB1b

PASS regression

promiscuous re-armed on the second tool start after a stop

PASSF3

PASS regression

status-bar task slot cleared on a forced Geiger stop

PASSF7

PASS regression

Geiger refused to start under airplane mode; promisc stayed off

PASSF1

PASS regression

inline Scan refuses while this page's own tool runs, and starts a scan when idle

WARNF8

WARN regression

cannot test: the fullscreen reveal's audio is not playing, so an un-fired screensaver would prove nothing

PASSF4

PASS regression

Join WiFi stopped the Geiger honestly instead of deafening it

PASSF7b

PASS regression

scripted tool start refused under airplane mode; promisc off

PASSFB10

PASS regression

bt count 13 <= 50 distinct-address ceiling; dedup holding

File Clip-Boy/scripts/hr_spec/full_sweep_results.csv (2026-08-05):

id | verdict | self_rate | frames | dominant | self_is_dom | saw
0 | GOOD | 1.00 | 40 | 0 | 1 | 0x40
1 | GOOD | 0.82 | 38 | 1 | 1 | 1x31;0x7
2 | WRONGLOCK | 0.05 | 22 | 6 | 0 | 6x11;2x8;15x2
3 | WRONGLOCK | 0.00 | 1 | 5 | 0 | 5x1
4 | FAIL | 0.00 | 14 | 4 | 1 | 4x10;3x3;8x1
5 | GOOD | 0.97 | 40 | 5 | 1 | 5x40
6 | MARGINAL | 0.15 | 39 | 6 | 1 | 6x30;5x9
7 | GOOD | 0.67 | 24 | 7 | 1 | 7x24
8 | MARGINAL | 0.22 | 27 | 8 | 1 | 8x22;15x3;78x2
9 | GOOD | 1.00 | 34 | 9 | 1 | 9x34
10 | WRONGLOCK | 0.00 | 31 | 13 | 0 | 13x31
11 | MARGINAL | 0.17 | 23 | 11 | 1 | 11x14;13x5;77x4
12 | GOOD | 1.00 | 40 | 12 | 1 | 12x40
13 | GOOD | 0.75 | 40 | 13 | 1 | 13x40
14 | FAIL | 0.00 | 37 | 14 | 1 | 14x25;15x11;62x1
15 | GOOD | 1.00 | 40 | 15 | 1 | 15x40
16 | MARGINAL | 0.13 | 23 | 16 | 1 | 16x22;15x1
17 | MARGINAL | 0.13 | 15 | 89 | 0 | 89x5;1x4;17x2
18 | FAIL | 0.00 | 23 | 89 | 0 | 89x10;118x4;127x3
19 | WRONGLOCK | 0.00 | 49 | 127 | 0 | 127x49
20 | FAIL | 0.00 | 23 | 34 | 0 | 34x7;120x4;80x4
21 | FAIL | 0.02 | 42 | 21 | 1 | 21x31;93x11
22 | GOOD | 0.48 | 33 | 22 | 1 | 22x24;60x4;52x2
23 | FAIL | 0.09 | 33 | 23 | 1 | 23x30;87x1;39x1
24 | FAIL | 0.00 | 22 | 24 | 1 | 24x18;116x2;21x1
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

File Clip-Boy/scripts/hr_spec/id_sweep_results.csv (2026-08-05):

id | verdict | pings | scanned_as | note
15 | GOOD | <1 | The One Ring | correct
99 | GOOD | 1 | Legendary Conference Badge | correct
45 | GOOD | 1 | Alliance Warrant | correct
40 | GOOD | 2 | The Prophecy | correct
35 | GOOD | 2 | Floppy Disk | correct
41 | GOOD | 2 | Z-Staff | correct
92 | GOOD | 2 | Black Box | correct
46 | OK | 3 | Phone Booth Key Fob | correct
57 | OK | 3 | SG-1 Patch | correct
71 | OK | 5 | Sonic Screwdriver | correct
38 | MARGINAL | 7-8 | Oak's Notes | correct-but-slow
85 | MARGINAL | >5+backup | KARR CPU Fragment | correct-but-needs-distance
43 | FAIL | many | skynet's first thought (WRONG) | mis-decodes-reassign
11 | FAIL | 0.00 | 0
11 | FAIL | 0.00 | 0
11 | FAIL | 0.00 | 0
109 | FAIL | 0.00 | 0
109 | FAIL | 0.00 | 0
109 | FAIL | 0.00 | 0
109 | FAIL | 0.00 | 0
127 | FAIL | 0.00 | 0
127 | FAIL | 0.00 | 0
113 | FAIL | 0.00 | 0
113 | FAIL | 0.00 | 0
113 | FAIL | 0.00 | 0
110 | FAIL | 0.00 | 0
110 | FAIL | 0.00 | 0
110 | FAIL | 0.00 | 0
111 | FAIL | 0.00 | 0
111 | FAIL | 0.00 | 0
111 | FAIL | 0.00 | 0
127 | FAIL | 0.00 | 0
127 | GOOD | 1.00 | 56
125 | FAIL | 0.00 | 0
125 | GOOD | 0.37 | 35
125 | MARGINAL | 0.12 | 25
125 | GOOD | 0.31 | 36
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

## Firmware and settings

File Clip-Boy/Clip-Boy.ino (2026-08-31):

/*******************************************************************************
 * ui_test.ino - Clip-Boy V3 (Hardware Integration)
 *
 * Copyright (C) 2026 The Clip-Boy Authors
 *
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
 * Waveshare ESP32-S3-Touch-LCD-2.8 (320x240), LVGL 9.2
 * Uses LovyanInit-Waveshare for display/touch init.
 *
 * V3: Full hardware integration:
 *   - ClipBoyMarauder for WiFi/BT hacking functions
 *   - Adafruit_NeoPixel for 8 LEDs (4 fuse + 4 front)
 *   - audio-tools for I2S tone generation (theremin)
 *   - SparkFun_VL53L5CX for theremin distance sensing
 ******************************************************************************/

#include "cb_log.h"        // CB_LOG* — status notices silenced in release (kept in --test)

// H1: true once a USB host has actually drained our CDC TX (see cb_serial_tx_relax below).
// Declared up here so the test harness can report it -- without a read-back, "the badge got
// faster" and "the badge was never reflashed" are indistinguishable readings.
static bool cb_serial_seen = false;
// millis() at which a host first drained us, or 0 if never. The BOOLEAN ALONE IS USELESS as a
// control: the very act of connecting to read it latches it true, so "the fix was in force all
// window" and "the fix never engaged" both report true. The TIMESTAMP separates them --
// (uptime - cb_serial_seen_ms) small means it only latched when the reader attached just now.
static uint32_t cb_serial_seen_ms = 0;
// Runtime gate for CB_LOG chatter (extern'd in cb_log.h). The harness raises it
// around binary transfers so core-0 tasks can't splice log lines into the
// screenshot/audio byte stream (USB-CDC session-desync fix).
volatile bool cb_serial_quiet = false;

// Enlarge the Arduino loopTask stack from the 8KB default to 16KB. Deep tool paths
// run synchronously in loop() (the serial cmd handler / a UI tap dispatches into
// ClipBoy) and Evil Portal START in particular -- cold-WiFi init + AP bring-up +
// ~12 captive-portal handler registrations + DNS + String ops -- sits right at the
// 8KB limit and INTERMITTENTLY overflowed it: "Stack canary watchpoint triggered
// (loopTask)" -> reboot (backtrace pointed at the RTOS switch, canary=0xa5a5a5a5).
// 16KB gives ample headroom for the deepest tool path. (Root-cause fix for the
// Evil Portal start reboot; helps any deep tool.)
SET_LOOP_TASK_STACK_SIZE(16 * 1024);
#include <ws_lcd_setup.h>
#include <WiFi.h>
#include <SPIFFS.h>       // ClipBoy's data partition -- mounted/formatted early (before the
#include <LittleFS.h>     // startup sound) so a first-boot format never starves the audio task
#include "BAT_Driver.h"
#include "PWR_Key.h"

// ─── Hardware pin definitions ──────────────────────────────────────────────
#include "clipboy_pins.h"

// ─── ClipBoy/Marauder ─────────────────────────────────────────────────────
#include <ClipBoyMarauder.h>
#include "CommandLine.h"
ClipBoyMarauder cb;
CommandLine cli_obj;

// ─── Theme (no cross-deps) ──────────────────────────────────────────────────
#include "ui_theme.h"

// ─── Persistent config (NVS) ────────────────────────────────────────────────
#include "ui_config.h"
#include "arg_core.h"      // DC34 ARG: progress state, per-badge MAC, unlock gate

// ─── Collectibles data system ──────────────────────────────────────────────
#include "ui_collectibles.h"

// ─── Hardware drivers (depend on ui_config.h for cfg struct) ───────────────
#include "neopixel_driver.h"
#include "audio_driver.h"

// ─── Tool "More Info" descriptions ──────────────────────────────────────────
#include "tool_info.h"

// ─── Navigation + all UI code ───────────────────────────────────────────────
#include "ui_nav.h"

// ─── DC34 ARG: clipcli dispatcher + puzzle modules (after ui_nav for UI use) ──
#include "arg_clipcli.h"
#include "arg_p2_hack.h"
#include "arg_p3_dork.h"
#include "arg_p4_captcha.h"
#include "arg_unlock.h"        // P5 per-badge HMAC crypto (nonce-based, matches IVR)
#include "arg_p5_call.h"

// ─── Test harness (conditional, enabled via -DTEST_HARNESS build flag) ──────
#ifdef TEST_HARNESS
#include "test_harness.h"
#endif

// ─────────────────────── SETUP ──────────────────────────────────────────────

void setup() {
    Serial.begin(115200);
    // Native USB-CDC: cap TX blocking so a slow/absent reader can't stall the loop
    // into a watchdog reboot. Without this, a full TX buffer (verbose --test logging
    // outracing the reader, OR a USB host that enumerates the CDC but never reads it)
    // blocks Serial.write for seconds -> loop stalls -> reboot. 50ms delivers logs to
    // an active reader while dropping under pressure instead of hanging.
    Serial.setTxTimeoutMs(50);
    delay(200);
    Serial.println("\n=== CLIP-BOY V3 (HARDWARE INTEGRATION) ===");
    // ⚠ The 50 ms above is KEPT for the whole of setup() on purpose: the boot banner on
    // the line above is what production/flash_core.py's read_boot_banner() greps for, and
    // dropping to 0 here would make that WARN column noisy across the remaining fleet
    // flashes. cb_serial_tx_relax() at the END of setup() takes it to 0.

    BAT_Init();
    PWR_Init();

    if (!lcd_init()) {
        CB_LOGLN("[FAIL] Display init failed!");
        while (1) delay(100);
    }
    CB_LOGLN("[OK] Display + touch + LVGL initialized");

    // Global tap sound: one indev hook plays a click for every lv_button-class
    // widget, so no individual button needs to register its own callback.
    ui_install_global_click_sound();

    // Mask the black screen during the ~5s blocking ClipBoy init.
    //   normal build: mascot splash (stays up through the init).
    //   rift build:   rift ~1.5s, then draw Clippy -- Clippy then sits frozen
    //                 masking the init (it's static, so the freeze is invisible).
#ifdef BADGE_QUANTUM_RIFT
    rift_show_static();
    rift_pump(RIFT_HOLD_MS);   // rift "opening" beat ~1.5s
    rift_show_clippy();        // draw Clippy; the init below runs behind it
#else
    show_boot_splash();
#endif

    // Load saved settings from NVS
    cfg_load();
    // Apply the saved time zone before anything can render a clock. NTP has not
    // run yet and may never run, but tzset() is local and free, and doing it here
    // means the zone is already right whenever the first sync does land.
    cb_tz_apply();
    hr_cal_load();      // restore per-zone LiDAR flat-field calibration
    cfg_prefs.begin(CFG_NAMESPACE, true);   // handle is closed after cfg_load(); open our own
    coll_filter_collected_only = cfg_prefs.getBool("collfilt", false);  // restore Collectibles All/Found view
    cfg_prefs.end();

    // Bring audio up EARLY (right after config load) so the startup sound plays ASAP --
    // during the slow WiFi auto-connect + ClipBoy init below -- at the saved volume, unless
    // muted. audio_init is self-contained (I2S + PSRAM + its own core-0 task) and no-ops if
    // called twice, so this is safe ahead of cb.begin()/neo_init().
    audio_init(cfg.volume / 100.0f);
    cfg_boot_tick();   // bump the (capped) boot counter (radio reminder rule)

    // FORMAT-BEFORE-SOUND. On the first boot after a fresh flash a blank data partition
    // is FORMATTED on its first mount; an ESP32-S3 flash erase disables the flash cache,
    // which stalls the flash-resident core-0 audio task -> the startup PCM underruns and
    // the sound stutters ("CPU pegged"). Crucially, a browser Factory flash writes littlefs
    // but NOT ClipBoy's SPIFFS, so on that path SPIFFS is the partition that formats and
    // starves the audio -- which a littlefs-only check misses. Fix: mount/format BOTH data
    // partitions HERE, synchronously, BEFORE the sound plays. On a normal boot both mount
    // instantly (no format) -> the sound still greets you immediately; on a first/format
    // boot the format completes first (the boot mascot lingers a beat) -> the sound then
    // plays CLEANLY, never contended. Covers every path (Factory, erase_region, SD-less)
    // regardless of flash order, and (unlike the old skip) the chime plays on EVERY boot.
    // Both begins are idempotent -> cb.begin()/coll_init() below reuse the mounts (no-op).
    // Explicit "littlefs" label dodges the SPIFFS/LittleFS mount-label confusion (lv_conf note).
    uint32_t fmt_t0 = millis();
    bool lfs_ok    = LittleFS.begin(true, "/littlefs", 10, "littlefs");  // our 7.4MB (radio beds)
    bool spiffs_ok = SPIFFS.begin(true);                                 // ClipBoy's 448KB data
    CB_LOGF("[BOOT] reset=%d littlefs=%d spiffs=%d fmt=%lums -> startup sound %s\n",
            (int)esp_reset_reason(), lfs_ok, spiffs_ok,
            (unsigned long)(millis() - fmt_t0), cfg.sound ? "play" : "muted");
    if (!cfg.sound) audio_set_volume(0.0f);
    else            audio_mp3_play(startup_mp3, startup_mp3_len, false);
    arg_core_init();   // DC34 ARG progress + per-badge MAC (after NVS available)
    arg_init();        // P5 crypto: load/generate per-badge nonce + unlock state (NVS)
    arg_clipcli_init();// wire challenge/hint/reset dispatch to the puzzle registry
    p2_register();     // P2 (hacking puzzle)
    p3_register();     // P3 Dork
    p4_register();     // P4 Captcha
    p5_register();     // P5 The Call (wires clipcli unlock)
    wifi_creds_load();

    // Check for saved WiFi credentials (reboot-to-connect flow).
    // Must happen BEFORE cb.begin() touches WiFi.
    {
        Preferences wp;
        wp.begin("wifi_join", true);  // read-only
        String saved_ssid = wp.getString("ssid", "");
        String saved_pw   = wp.getString("pw", "");
        wp.end();

        if (saved_ssid.length() > 0) {
            CB_LOGF("[WIFI] Auto-connecting to: %s\n", saved_ssid.c_str());
            WiFi.mode(WIFI_STA);
            WiFi.begin(saved_ssid.c_str(),
                       saved_pw.length() > 0 ? saved_pw.c_str() : NULL);

            // Wait up to 10s for connection
            int tries = 0;
            while (WiFi.status() != WL_CONNECTED && tries < 20) {
                delay(500);
                Serial.print(".");
                tries++;
            }
            if (WiFi.status() == WL_CONNECTED) {
                CB_LOGF("\n[WIFI] Connected! IP: %s\n",
                    WiFi.localIP().toString().c_str());
                // Save SSID for display, clear creds from NVS
                strncpy(wifi_join_ssid, saved_ssid.c_str(), sizeof(wifi_join_ssid) - 1);
            } else {
                CB_LOGLN("\n[WIFI] Auto-connect failed");
                WiFi.disconnect();
            }
            // Clear saved creds - one-shot
            Preferences wpc;
            wpc.begin("wifi_join", false);
            wpc.clear();
            wpc.end();
        }
    }

    // Ensure Arduino WiFi layer is fully initialized (event loop, STA netif,
    // event handlers) BEFORE cb.begin().  ClipBoy's RunSetup calls esp_wifi_init /
    // set_mode / start DIRECTLY (bypassing Arduino), and on IDF 4.4+ it does NOT
    // create the default event loop or STA netif.  Once esp_wifi_start succeeds
    // the --wrap linker shims lock _cb_wifi_hw_up=true, making all subsequent
    // esp_wifi_init/start/set_mode calls no-ops - including the ones inside
    // Arduino's WiFi.mode().  If Arduino never gets a chance to run its low-level
    // init first, the event loop and netif are missing, and esp_wifi_connect()
    // later crashes on Core 0 (InstrFetchProhibited @ PC 0x00000000) when the
    // WiFi task tries to dispatch events through a null handler.
    //
    // Calling WiFi.mode(WIFI_STA) here triggers Arduino's wifiLowLevelInit(),
    // which creates the event loop, STA netif, and registers event handlers.
    // This happens before cb.begin() locks everything out.  If the auto-connect
    // block above already called WiFi.mode(), this is a harmless no-op.
    //
    // Boot STA-only (NOT AP_STA): Sn34k-Boy is listen-only and must transmit
    // nothing, and an APSTA badge beacons a default 'ESP_xxxxxx' AP while idle.
    // The active-transmit tools (Res34rch-only) need the AP interface for
    // esp_wifi_80211_tx(WIFI_IF_AP,...), so they switch to APSTA ON DEMAND at
    // tool start (cb.setRawTxMode(true) in dispatch_clipboy_action) and restore
    // STA on stop (cb_stop_operation) -- no AP is broadcast when idle. That
    // on-demand switch uses __real_esp_wifi_set_mode to bypass the --wrap shim
    // that would otherwise no-op it (which is the bug that left every WIFI_IF_AP
    // transmit radiating nothing when the badge was locked to STA-only).
    WiFi.mode(WIFI_STA);
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
void loop() {
    cb_serial_tx_relax();
    PWR_Loop();   // power button: medium hold = restart, >=3s = shutdown (latch)
    {
        cb.loop();
        lv_timer_handler();
#ifdef TEST_HARNESS
        th_fps_tick();
#endif
        screensaver_tick();
        hr_cal_tick();   // finalize a pending sensor calibration (may stop the scan)
        if (hr_scanning) {
            hr_scanner.tick();

            // Feed the overlay heatmap; drive our bottom-left level bubble
            // (the overlay's corner bubble is disabled -- showLevelBubble=false).
            hr_scanner.feedOverlaySensor();
            float roll = 0.0f, pitch = 0.0f;
            if (hr_imu_ok) hr_imu.readLevel(roll, pitch);
            hr_level_update(roll, pitch);

            // While the engine has the user's tag in view (orient marker
            // found -> 'Hold Steady' prompt), bump the scan-timeout
            // forward. progress > 0 alone misses the case where the
            // orient marker is found but CRC keeps failing -- the
            // engine still wants the user to hold steady.
            const auto &r = hr_scanner.result();
            if (r.prompt == HRScan::Prompt::HoldSteady ||
                r.progress > 0) {
                hr_scanner.resetTimeout();
            }

            // Scanner auto-stops on lock, timeout, or unknown ID. Three paths:
            //   - real timeout: library's own timedOut flag with no valid lock
            //   - unknown code: hr_lock_cb saw a decode whose ID isn't in our
            //     collectibles list (e.g. physical code 128 vs our 1-100 range)
            //   - success: a valid collectible ID locked and was persisted
            if (!hr_scanner.isEnabled()) {
                const auto &res = hr_scanner.result();
                const bool real_timeout = res.timedOut && res.lockedId < 0;
                const int  unknown_id   = real_timeout ? -1 : hr_scan_last_invalid_id;
                const char *path = real_timeout ? "TIMEOUT"
                                 : unknown_id >= 0 ? "UNKNOWN"
                                 : "SUCCESS";
                CB_LOGF("[HR] Scan ended: timedOut=%d lockedId=%d unknownId=%d -> %s\n",
                              (int)res.timedOut, res.lockedId, unknown_id, path);
                if (real_timeout) {
                    audio_sonar_stop();
                    if (cfg.sound) audio_mp3_play(scan_stop_mp3, scan_stop_mp3_len, false);
                    hr_scan_timeout_cleanup();
                } else if (unknown_id >= 0) {
                    audio_sonar_stop();
                    if (cfg.sound) audio_mp3_play(scan_stop_mp3, scan_stop_mp3_len, false);
                    hr_scan_unknown_cleanup(unknown_id);
                    hr_scan_last_invalid_id = -1;
                } else {
                    // Lock fired on a valid ID - scan_ok already playing; let
                    // it finish while a "Found: <title>" banner is held for
                    // ~1.6s so the user sees what they unlocked.
                    hr_scan_success_cleanup(res.lockedId);
                }
            }
        }
        // neo_animation_tick() now runs on core 0 via neo_start_core0_task()
        audio_loop();
    }

    // Serial CLI - our commands + Marauder CLI
    if (Serial.available()) {
#ifdef TEST_HARNESS
        // Test harness intercepts STX-prefixed commands
        if (test_harness_process_serial()) { /* handled */ }
        else
#endif
      {
        String line = Serial.readStringUntil('\n');
        line.trim();
        if (line.length() > 0) {
            bool handled = false;
            // DC34 ARG: capture follow-up lines (confirm Y/N, in-session) or any
            // line starting with "clipcli". (handoff §2.2/§2.4)
            if (arg_is_capturing() || line.startsWith("clipcli")) {
                arg_clipcli_line(line.c_str());
                handled = true;
            }
#ifdef COLL_DEBUG
            if (line.startsWith("coll ")) {
                coll_process_serial(line);
                handled = true;
            }
#endif
#ifdef RADIO_PCM_TEST
            if (!handled && line == "radiolfs") {   // seed + stream from littlefs (perf test)
                radio_pcm_test_lfs();
                handled = true;
            }
            if (!handled && line == "radioprog") {   // stream from PROGMEM (A/B baseline)
                audio_pcm_play(radio_test_pcm_ulaw, radio_test_pcm_len, radio_test_pcm_rate, false);
                handled = true;
            }
            if (!handled && line == "radiostop") {
                audio_pcm_stop();
                handled = true;
            }
#endif
#ifdef TEST_HARNESS
            if (!handled && line == "glyphtest") {   // SSID/glyph substitution test screen
                show_glyph_test();
                handled = true;
            }
            if (!handled && line == "stationtest") {  // radio "new station detected" modal (real path)
                radio_announce_one(4, false);   // Pirate 0x7C00; View navigates to the radio + tunes it
                handled = true;
            }
            if (!handled && line.startsWith("settheme ")) {  // apply theme by index (prototype)
                int n = line.substring(9).toInt();
                ui_theme_switch_live((uint8_t)n);   // proper teardown (deletes old scr_main +
                                                    // status_timer) -- matches the real dropdown;
                                                    // apply+create_main_screen leaked them each call
                CB_LOGF("[THEME] applied %d (%s)\n", n,
                              (n >= 0 && n < NUM_THEMES) ? theme_presets[n].name : "?");
                handled = true;
            }
            if (!handled && line.startsWith("gototab ")) {   // nav div+tab (for screenshots)
                int d = line.substring(8).toInt();
                int sp = line.indexOf(' ', 8);
                int t = (sp > 0) ? line.substring(sp + 1).toInt() : 0;
                goto_div_tab((uint8_t)d, (uint8_t)t);
                CB_LOGF("[NAV] div %d tab %d\n", d, t);
                handled = true;
            }
            if (!handled && line.startsWith("therem ")) {    // theremin on/off (verify voice-lock)
                String a = line.substring(7); a.trim();
                if (a == "on") CB_LOGF("[THEREMIN] enable=%d\n", theremin_enable());
                else { theremin_disable(); CB_LOGLN("[THEREMIN] disabled"); }
                handled = true;
            }
            if (!handled && line.startsWith("rubduck ")) {   // rubber-duck LED theme on/off
                String a = line.substring(8); a.trim();
                if (a == "on") { led_apply_rubber_duck(); CB_LOGLN("[LED] rubber duck ON"); }
                else { led_apply_preset(4); CB_LOGLN("[LED] off"); }
                handled = true;
            }
            if (!handled && line == "p5code") {   // reveal THIS badge's expected P5 code (debug/test only)
                char c[9]; arg_code_for_nonce(arg_nonce, c);
                Serial.printf("[P5TEST] nonce=%04u code=%s\n", arg_nonce, c);
                handled = true;
            }
            if (!handled && line == "p3pass") {   // reveal THIS badge's P3 Queue passphrase (debug/test only)
                char w[8]; p3_passphrase(w);
                Serial.printf("[P3TEST] passphrase=%s\n", w);
                handled = true;
            }
            if (!handled && line == "p5screen") {  // show the P5 numpad (render test)
                show_p5_numpad();
                Serial.println("[P5TEST] numpad shown");
                handled = true;
            }
            if (!handled && line == "secret") {  // fire the secret-menu reveal (render test)
                if (arg_reveal_keypad_fn) arg_reveal_keypad_fn();
                Serial.println("[ARGTEST] secret-menu keypad revealed");
                handled = true;
            }
            if (!handled && line == "p3map") {   // dump the full P3 text-adventure map (rooms/items/NPCs/verbs)
                p3_map_dump();
                handled = true;
            }
            if (!handled && line == "pcapstart") {   // DC34-147 PCAP capture test
                cb.setSavePCAP(true);
                cb.setChannel(1);
                cb.sniffRaw();                        // raw packet monitor -> startPcap
                Serial.println("[PCAPTEST] capture started (ch1, raw). Run 'pcapstop' after a few seconds.");
                handled = true;
            }
            if (!handled && line == "pcapstop") {     // DC34-147 stop + verify .pcap
                cb.stopScan();
                auto verify = [](fs::FS &fsx, const char *label) {
                    File root = fsx.open("/");
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

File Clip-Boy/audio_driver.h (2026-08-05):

#pragma once
// audio_driver.h — Header-only audio driver for Clip-Boy badge
//
// Uses audio-tools library (selective includes to avoid namespace conflicts
// with AsyncTCP/ClipBoy). Provides:
//   - I2S tone generation for theremin
//   - MP3 playback from PROGMEM via minimp3 decoder (public-domain / CC0;
//     replaced libhelix to drop its GPL/RPSL copyleft from the build)
//
// Included from ui_test.ino AFTER clipboy_pins.h.

// Include config first so USE_URL_ARDUINO gets defined, then kill it
// before CoreAudio.h pulls in AudioHttp → esp_http_client → http_parser
// which conflicts with ESPAsyncWebServer's HTTP_DELETE/HTTP_GET defines.
#include <AudioToolsConfig.h>
#undef USE_URL_ARDUINO
#undef USE_AUDIO_SERVER
#include <AudioTools.h>
// minimp3 directly (public domain / CC0). We do NOT use audio-tools' streaming
// MP3 wrapper -- its chunked decode() spins forever on a partial frame. Instead
// each short sound is decoded whole to PCM (aud_mp3_decode) and streamed raw.
// MINIMP3_IMPLEMENTATION is compiled once in minimp3_impl.cpp.
#include "minimp3.h"
// Streaming MP3 decoder core (shared with the host proof scripts/tests/
// mp3_stream_host.c). Lets multi-minute radio beds decode frame-by-frame from a
// file instead of whole-into-PSRAM (78 s @ 8 kHz would be ~14 MB). CC0.
#include <FS.h>
#include "mp3_stream.h"
#include <SparkFun_VL53L5CX_Library.h>
#include <ClipBoyTheremin.h>

#include "clipboy_pins.h"

// Sound data (PROGMEM)
#include "snd_scan_search_mp3.h"
#include "snd_scanning_mp3.h"        // Jeff Kaale via upbeat.io -- looping scan bed (trial)
#include "snd_scan_ok_mp3.h"
#include "snd_scan_stop_mp3.h"

using namespace audio_tools;

// ─── State ─────────────────────────────────────────────────────────────────

static I2SStream                       aud_i2s;
static VolumeStream                    aud_volume(aud_i2s);

// ClipBoyTheremin library instance
ClipTheremin::Theremin                 aud_theremin;
static volatile bool                   aud_theremin_active = false;

// SB3 -- a UI tap click used to KILL a running theremin permanently.
//
// audio_mp3_play() pre-empts the theremin because both share the single I2S render
// stream, but audio_theremin_stop() is a bare flag clear with no re-arm anywhere except
// theremin_enable(). So any tap on a button-class widget (the always-present status-bar
// FL / ? buttons) silenced the synth for good, while the poll timer and sensor stayed up
// -- the button still read "Disable", the status bar still said active, and the four bars
// FROZE at their last values. Reads as a hang, not a stop. Owner-confirmed on hardware
// 2026-07-25 (flashlight lit + tone died + bars frozen).
//
// Two flags now, because ONE cannot express the difference:
//   aud_theremin_want   = user-level intent (Enable/Disable). Owned by core 1.
//   aud_theremin_active = is the core-0 task rendering it right now.
// A short clip clears `active` and leaves `want` set; the audio task restores `active`
// from `want` once no clip owns the stream. want=true + active=false outside a clip is
// the SB3 signature, which is what makes it testable rather than audible-only.
//
// CB_THEREMIN_DUCK_CLICK 0 = taps are simply SILENT while the theremin runs (audio_play_click
// early-returns before it ever reaches audio_mp3_play, so the synth is untouched).
// 1 = duck-and-resume: the click plays and the core-0 task restores the synth when the clip
// drains (~100 ms gap), matching the contract the geiger already honors.
// **DEFAULT IS 0 — owner's call after hearing both on hardware (2026-07-26): "taps going silent
// is the right move."** The audible cost is small by construction: this only mutes the
// status-bar FL and ? buttons, because sliders are excluded from the click hook and the voice
// dropdowns are locked while the theremin runs. Flip to 1 for duck-and-resume; both paths are
// implemented and tested, and SB3's regression test passes either way (it asserts the synth is
// still running after a tap, which is true of both).
#ifndef CB_THEREMIN_DUCK_CLICK
  #define CB_THEREMIN_DUCK_CLICK 0
#endif
static volatile bool                   aud_theremin_want   = false;

// MP3 playback state — each sound is decoded whole to raw PCM (stereo int16 @
// AUD_RATE) on play, then the task streams it to I2S. No streaming decoder in
// the hot path.
#define AUD_RATE 44100
static int16_t * volatile              aud_mp3_pcm     = NULL;  // PSRAM, stereo interleaved
static volatile size_t                 aud_mp3_frames  = 0;     // stereo frames
static volatile size_t                 aud_mp3_pos     = 0;     // current stereo frame
static volatile bool                   aud_mp3_loop    = false;
static volatile bool                   aud_mp3_active  = false;

static bool   aud_initialized = false;

// Mutexes for cross-core safety
static SemaphoreHandle_t aud_mp3_mutex     = NULL;  // protects MP3 state transitions
static SemaphoreHandle_t aud_theremin_mutex = NULL;  // protects theremin feed/render

// MP3 task on core 0
static TaskHandle_t aud_mp3_task_handle = NULL;

// ─── Synthesized geiger ticks ──────────────────────────────────────────────
// Renders damped-sine click transients directly to I2S, Poisson-ish timing
// driven by aud_geiger_rate (clicks/sec). Replaces the MP3-based geiger that
// suffered from decoder-reinit pops when switching intensity segments.
static volatile bool     aud_geiger_active = false;
static volatile uint16_t aud_geiger_rate   = 0;
// Owned exclusively by the audio task — no mutex needed:
static uint32_t aud_geiger_phase_samp = 0;   // samples into current click (0 = idle)
static float    aud_geiger_phase_rad  = 0.0f;
static uint32_t aud_geiger_next_samp  = 0;   // samples until next click fires

static const uint32_t GEIGER_CLICK_SAMPLES = 441;      // ~10ms @ 44.1kHz
static const float    GEIGER_CLICK_FREQ    = 2500.0f;  // Hz — crisp tik
static const float    GEIGER_DECAY         = 0.012f;   // per-sample exp decay
static const float    GEIGER_AMPLITUDE     = 24000.0f; // peak int16 ~73%
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

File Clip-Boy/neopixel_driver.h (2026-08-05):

#pragma once
// neopixel_driver.h — NeoPixel driver for Clip-Boy badge
//
// 8 physical WS2812B LEDs: 4 fuse (0-3) + 4 front (4-7).
// Fuse layout: 0=BL, 1=BR, 2=TR, 3=TL. Fiber pairs: 0↔3 (left), 1↔2 (right).
//
// Animations: 0=None (static), 1=Breathe, 2=Chase
// Chase: colors crossfade around a ring. Fuse warp-core order: 0→3→2→1→0
//        (BL→TL→TR→BR, flowing through both fiber pairs).
//
// Included from ui_test.ino AFTER ui_config.h and clipboy_pins.h.

#include <Adafruit_NeoPixel.h>
#include "clipboy_pins.h"

static Adafruit_NeoPixel neo_strip(CB_NEOPIXEL_COUNT, CB_NEOPIXEL_PIN,
                                    NEO_GRB + NEO_KHZ800);

// Per-LED breathe phase
static float neo_breathe_phase[CB_NEOPIXEL_COUNT] = {};

// Chase state
static float neo_chase_phase = 0.0f;

// ─── Rubber Duck theme ─────────────────────────────────────────────────────
// All LEDs ducky-yellow except an orange "head" + a black LED trailing it,
// chasing along front 4-1 then fuse 4,3,2,1, then repeating. A global effect
// (not expressible per-LED), so it takes over the render when active.
static bool    neo_rubber_duck_active = false;
static float   neo_rd_pos = 0.0f;               // continuous head position (crossfade, not hop)
// front 4,3,2,1 = LED idx 7,6,5,4 ; fuse 4,3,2,1 = idx 3,2,1,0
static const uint8_t neo_rd_path[CB_NEOPIXEL_COUNT] = {7, 6, 5, 4, 3, 2, 1, 0};
#define NEO_RD_STEP_MS  190                     // pace: ms per step

// Dirty flag — skip show() when nothing changed
static bool neo_dirty = false;

// Flashlight mode: when true, LEDs 4-7 (the 4 front-facing) are forced
// to full white, overriding whatever animation/color they're configured for.
// RAM-only state, resets to off on boot. Toggled via status-bar button.
static volatile bool neo_flashlight_active = false;

static inline void neo_flashlight_set(bool on) { neo_flashlight_active = on; }
static inline bool neo_flashlight_is_on(void)  { return neo_flashlight_active; }
static inline void neo_flashlight_toggle(void) { neo_flashlight_active = !neo_flashlight_active; }

// ─── Scan sweep (KITT / Cylon "Larson scanner") ────────────────────────────
// While a collectible scan runs, the 4 FRONT LEDs (idx 4-7) drop to black and a
// red (255,0,0) "eye" sweeps 4→7→4, ping-pong, with a short decay TRAIL (the LED
// the eye just left fades toward black over ~1 LED rather than snapping off).
// Front-4 override only — the fuse LEDs (0-3) keep their normal animation.
// Rendered from the core-0 task (the ONLY core that may touch neo_strip, same as
// the flashlight); the caller gates it on the front LEDs actually being lit.
static volatile bool neo_scan_sweep_active = false;
static uint8_t neo_scan_red[4] = {0, 0, 0, 0};   // decay buffer: red level per front LED
static float   neo_scan_pos    = 0.0f;           // eye position 0..3 across the front 4
static int8_t  neo_scan_dir    = 1;              // +1 = 4→7, -1 = 7→4
static volatile int8_t neo_scan_sweep_force = -1; // A/B override (serial led_sweep): -1 auto, 0 off, 1 on
#define NEO_SCAN_SPEED_LPS    3.0f               // eye speed (LEDs/sec; crosses the 4 in ~1s). Slowed from
                                                 // 6.0: the front LEDs share the sensor's face + reflect off
                                                 // the held-up tag into the SPADs, and a fast-moving bright
                                                 // point modulates the per-zone ambient faster than the
                                                 // sensor can track -> slower lock. A stately KITT is gentler.
#define NEO_SCAN_TRAIL_TAU_MS 130.0f             // trail decay time-constant (longer, to suit the slower eye)
#define NEO_SCAN_PEAK         64                 // peak emitted red (0-255) cap. Keeps the eye visibly red but
                                                 // reflects far less light into the ToF FoV than the old full
                                                 // 180. (User brightness still lowers it further; never raises.)

static inline void neo_scan_sweep_set(bool on) {
    if (on && !neo_scan_sweep_active) {          // rising edge: reset the eye to the left end
        neo_scan_pos = 0.0f; neo_scan_dir = 1;
        neo_scan_red[0] = neo_scan_red[1] = neo_scan_red[2] = neo_scan_red[3] = 0;
    }
    neo_scan_sweep_active = on;
}
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

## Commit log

2026-06-18 release integrity: update signed checksums (firmware 2026-06-18+f43008b)
    Re-cut release including the updated acceptable-use consent + Legal-page
    indemnity. SHA256SUMS + legacy-Ed25519 signature refreshed.
2026-07-17 web: landing hub (Help / Post-con / Source / brycebadges.com) + post-con 'live after DC34' placeholder
    Root index.html = the Clip-Boy home for GitHub Pages (safehazard.github.io/Clip-Boy):
    4 link cards. postcon/index.html = a public placeholder until the real (private) post-con
    companion is published after DEFCON 34.
2026-07-17 web: landing tagline -> 'DEF CON electronic badge / digital wasteland survivor soul'
2026-07-17 web: landing tagline -> 'Pick a vault.' on its own line (was wrapping)
2026-07-20 release: sums for 2026-07-20+6a04ec7
    Re-cut of all 4 variants. The prior release shipped the all-zero ARG placeholder
    key, which left the P5 phone-unlock step non-functional on every badge; this build
    carries the real key. Signed with the same rotated release key; verifies against
    keys/clipboy-release.pub.
2026-07-31 release(2026-07-31+ea2708d2): mirror signed SHA256SUMS + minisig
    Mirrored from tropicsquirrel/ui_test after web_flash deployed the bins (status
    stage=deployed, served_new=true). LF blob bytes, verified vs the pinned release key.
2026-08-05 Publish Clip-Boy firmware source (GPLv3) + open-hardware package
    GPLv3 Corresponding Source for the shipped badges (VERSION 2026-07-31+ea2708d2),
    now that badges are being distributed (BSides LV). Full firmware under Clip-Boy/ +
    the open-hardware package (BOM/gerbers/enclosure/OmniTag) + printable tag/stand
    models. Public edition: vanilla rift placeholder colorways + blank boot art (the
    KS-exclusive Quantum-Rift assets live in the private backer repo). The sn34k/
    res34rch firmware here is byte-for-byte the source the signed release was built
    from. No secrets (ARG HMAC key absent; secret.h.example only).
    - README replaced (placeholder -> real, with the flash.brycebadges.com skip-build link)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
    [1.3mf, 10.3mf, 100.3mf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]
2026-08-08 @ web: add "Flash Firmware" pill to landing (flash.brycebadges.com)
    New card on safehazard.github.io/Clip-Boy for existing badge owners to update
    firmware from the browser. Matches existing card markup/styling; placed after
    Source, before "Get your own".
    Claude-Session: https://claude.ai/code/session_01FpnaEo3y32q2c2jJUixApR
    @
2026-08-10 @ postcon: go live (DC34 over) -- real ARG solution page + landing card
    DEF CON 34 is over, so the post-con companion goes public:
    - postcon/index.html: the real solution page (all HR bump patterns + working P5
    unlock computer), generated by gen_postcon_site.py --publish with the real ARG
    key from secret.h. DO-NOT-PUBLISH banner, test-key warnings, and internal
    checklist stripped. Owner verified a P5 code against a live badge before push.
    - index.html: Post-Con card flipped from "after DEF CON 34 / goes live once the
    con is over" to present tense ("Live now").
    The ARG key is now public by design (WebCrypto computes P5 codes client-side).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
2026-08-31 readme: credit JustCallMeKoko / ESP32 Marauder
    The firmware forks ESP32 Marauder; add it (with a github link) to the README
    Credits section alongside the on-device credit. Owner request.
    Claude-Session: https://claude.ai/code/session_01DcwKnbDkHu62CrQ1nLzZ7A
2026-09-04 landing: add spec line, "Build your own" hardware vault, refresh footer
    - spec/readout line under the tagline (ESP32-S3, ToF, SAO 1.69bis, GPLv3 HW)
    - new "Build your own" card -> Clip-Boy/hardware (BOM/Gerbers/enclosure/PCB)
    - footer: "independent, original design; not affiliated/endorsed" + keep AUP link
    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
2026-09-04 landing: add favicon (badge logo)
    Copy shop favicon.png into the repo, link it from index.html
    (icon + apple-touch-icon).
    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
2026-09-04 landing: reorder cards (Source-first), drop "Pick a vault."
    Source, Build your own, Flash Firmware, Get your own, Help, Post-Con.
    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
2026-09-04 landing: sharpen Source/Build copy, add price to Get your own
    - Source now reads as the firmware/code; Build your own as the physical
    hardware (removes the redundant "your own" tail on both).
    - Get your own: "$135, second run pre-orders open".
    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
2026-09-04 landing: auto-hide "Get your own" when pre-orders close (13 Sept, Central)
    - Subtitle -> "$135, second run pre-orders close 13 Sept".
    - Inline script removes the card at 2026-09-14 00:00 CDT (05:00 UTC),
    i.e. after 23:59 on the 13th, Central. Client-clock dependent.
    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
2026-09-04 landing: reword "Get your own" at close instead of hiding it
    After 2026-09-14 00:00 CDT the card stays visible but its subtitle
    switches to point buyers at the open-hardware files above.
    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
2026-09-04 landing: hyphens instead of em dashes; retitle "Get your own" at close
    - Replace all &mdash; with plain hyphens.
    - After close (2026-09-14 00:00 CDT), title -> "Missed the run?" alongside
    the reworded subtitle.
    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
2026-09-04 landing: post-close title -> "Second run closed"
    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
2026-09-04 landing: trim post-close subtitle (drop repeated "second run closed")
    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
2026-09-04 landing: rename "Post-Con Companion" card to "Puzzles & Collectibles"
    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

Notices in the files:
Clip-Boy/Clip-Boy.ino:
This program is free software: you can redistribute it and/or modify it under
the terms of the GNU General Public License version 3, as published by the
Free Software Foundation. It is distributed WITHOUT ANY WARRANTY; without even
